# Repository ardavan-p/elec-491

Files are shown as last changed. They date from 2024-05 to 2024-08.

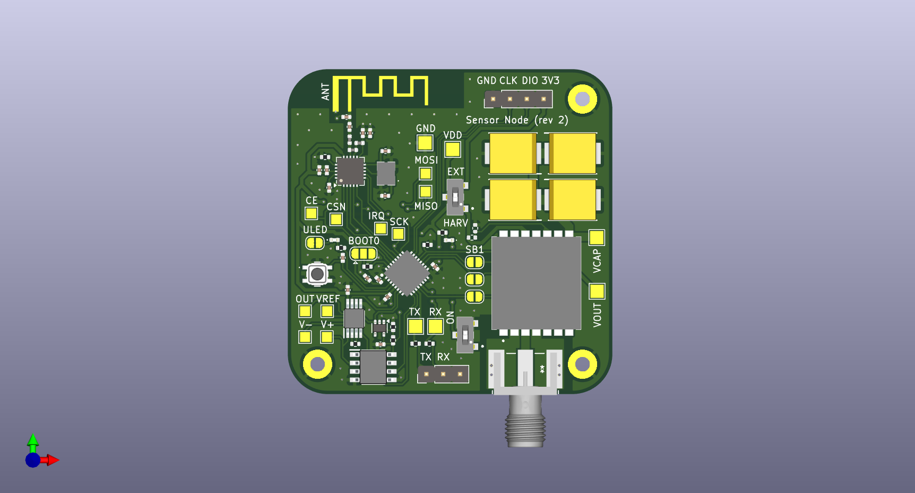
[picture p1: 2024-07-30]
sn/rev-2s/pcb/sensor-node-rev-2s/sensor-node-rev-2-img.png

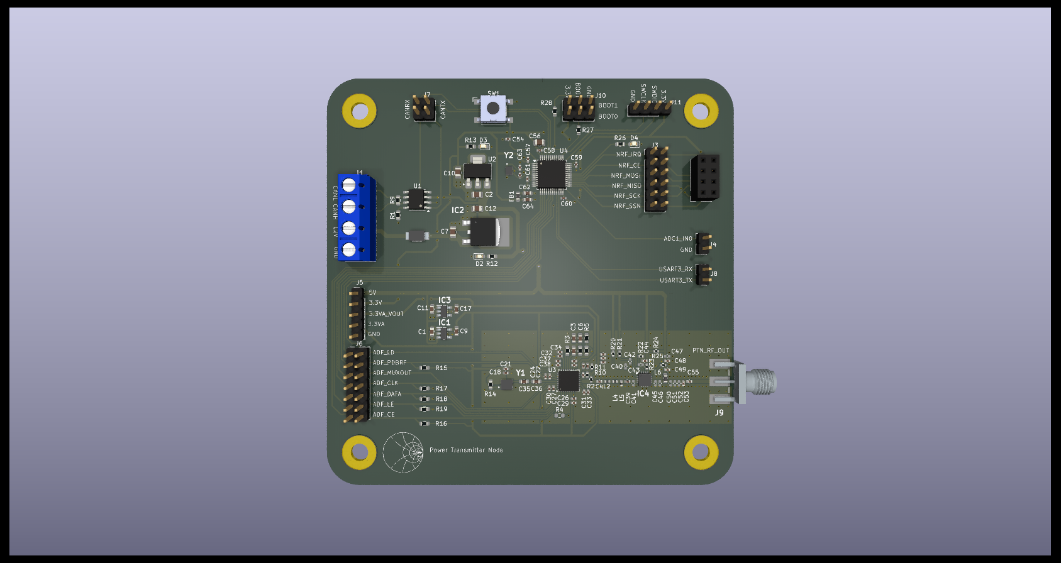
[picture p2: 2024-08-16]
video/scene3/ptn_image.png

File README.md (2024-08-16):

# ECE Capstone Project TL81 - Wirelessly Powered Tire Pressure Monitoring System

## Introduction
The following repository contains all design components for UBC ECE capstone project TL81 - Wirelessly Powered Tire Pressure Monitoring System

## Design Components
The following directories contain primary design components. 

### Graphical User Interface for TPMS
The source code for the GUI which was designed for demonstration purposes is located in the `gui/` folder. It is design in the Python.

### ECU Source Code
The firmware for the master ECU used in the demonstration is located in the `ecu/` folder. It is all written in C, for the STM32F103RCT6 microcontroller.

### Power Transmitter Node
All design files for the power transmitter node is located in the `ptn/` and `enclosure/ptn/` directories. <br>

The PCB design files for the power transmitter node are located in `ptn/pcb/`. The PCB is designed using the KiCad PCB design software. <br>

The firmware source code for the power transmitter node is located in `ptn/fw/`. It is all written in C, for the STM32F103C8T6 microcontroller. <br>

The physical enclosure for the power transmitter node is located in `enclosure/ptn/`. The PTN enclosure was designed using SolidWorks.

### Sensor Node
All design files for the sensor node is located in the `sn/` directory. <br>

The PCB design files for the sensor node are located in `sn/rev-2/pcb/sensor-node-v2/`. The PCB is designed using the KiCad PCB design software. <br>

The firmware source code for the final revision of the sensor node is located in `sn/rev-2/fw/sensor-node-v2/`. It is all written in C, for the STM32U031K8U6 microcontroller. <br>

## Capstone Video
All assets for the video created for this project is located in the `video/` folder.

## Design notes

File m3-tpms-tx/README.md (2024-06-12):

Contains the firmware for the TPMS sensor node.

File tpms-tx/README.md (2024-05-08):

Contains code for the prototype TPMS transmitter.

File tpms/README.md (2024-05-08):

Contains code for the prototype TPMS receiver.

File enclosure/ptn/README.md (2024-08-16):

# elec-391/enclosures/ptn

# Enclosure for the PTN

This directory includes the baseplate, top cover, and various PCB models (nRF24L014 and PTN PCBs) for the PTN enclosure.

The entire assembly is provided as a pack and go zip file, named "Assembly_pack_and_go.zip".

The two assembly components are also available as STL files for ease of viewing - "baseplate.STL" and "top_cover.STL".

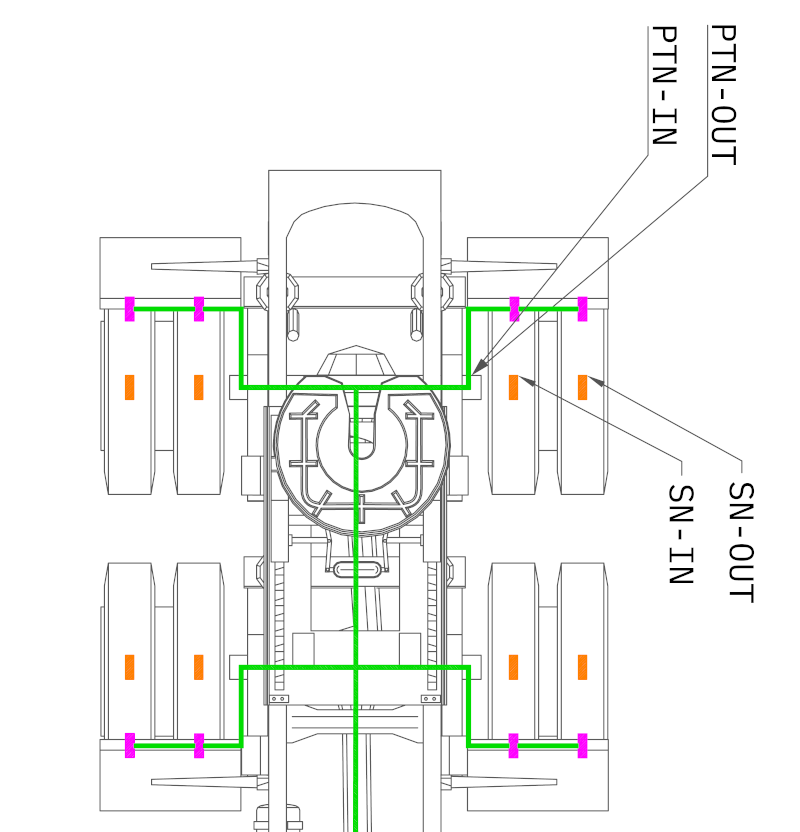
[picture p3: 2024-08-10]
gui/assets/truck-downsized.png

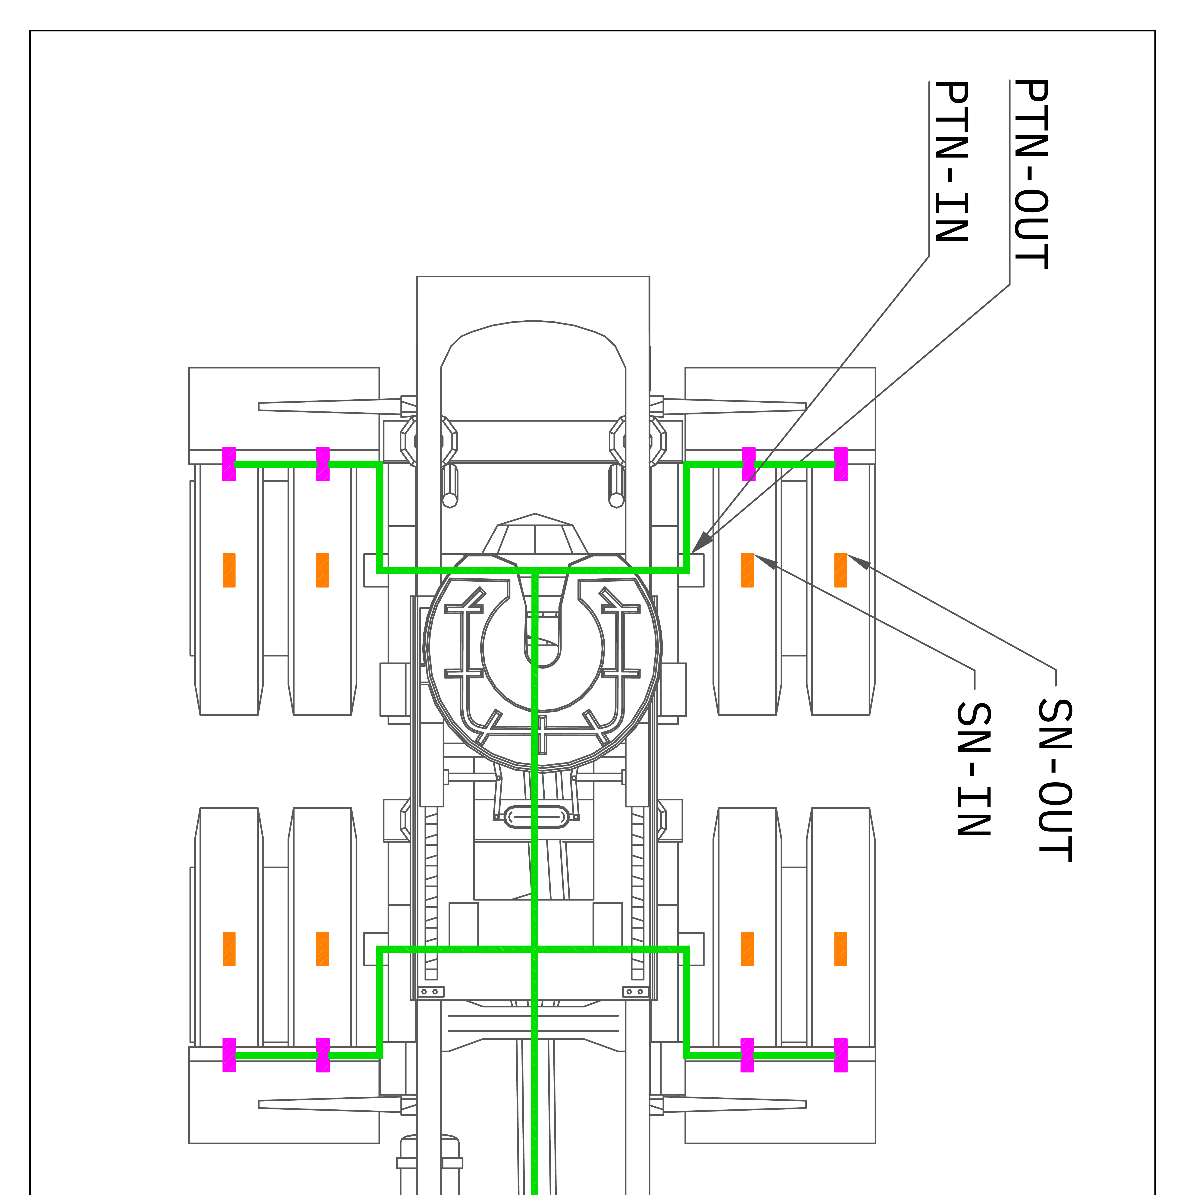
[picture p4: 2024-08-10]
gui/assets/truck.png

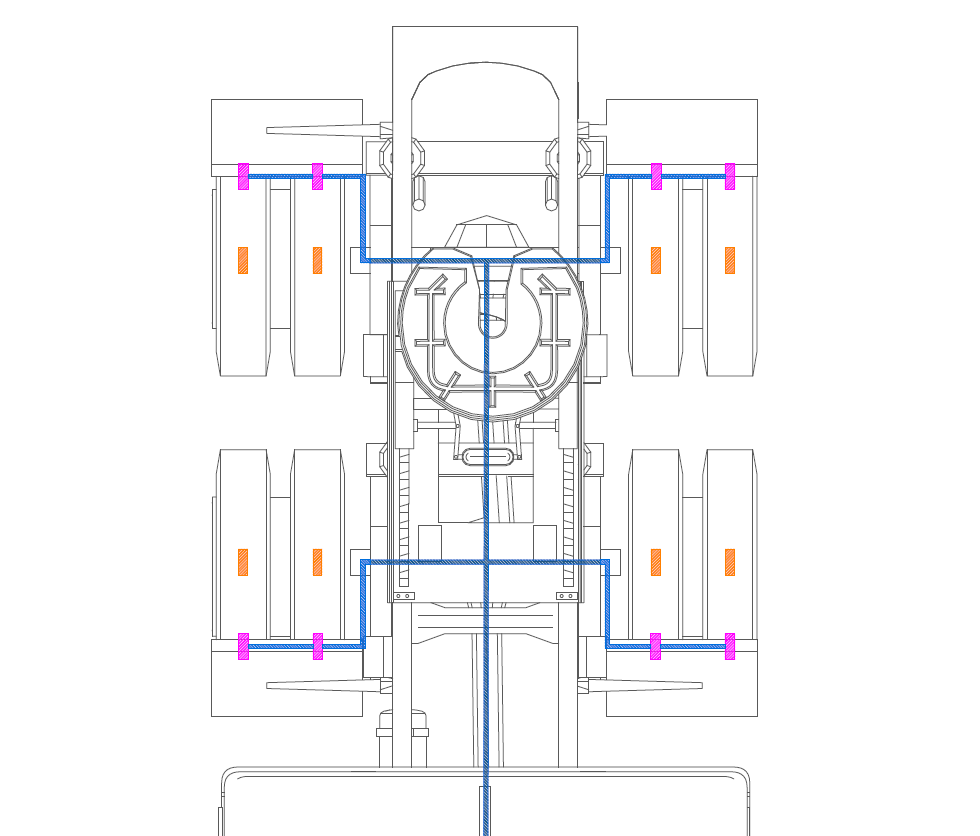
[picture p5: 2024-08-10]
gui/assets/gui_visual_v2.png

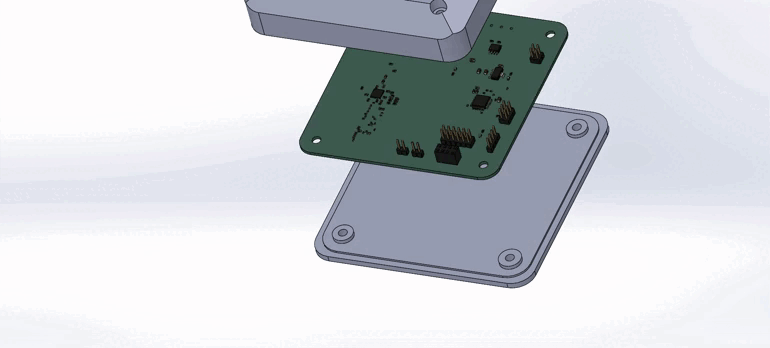
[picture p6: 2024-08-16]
enclosure/ptn/exports/Assem1.gif

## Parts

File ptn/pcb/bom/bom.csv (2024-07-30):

Reference | Guerrilla ID | Value | Description | Manufacturer_Name | Manufacturer_Part_Number | Mouser Part Number | Footprint | Qty | Datasheet | DNP
J1 |  | TB002-500-04BE | Fixed Terminal Blocks screw type, 5.00 , horizontal, 4 poles, CUI Blue, slotted screw, PCB mount | CUI Devices | TB002-500-04BE | 490-TB002-500-04BE | project_footprint_library:TB00250004BE_SCREW_TERMINAL | 1 | https://componentsearchengine.com/Datasheets/1/TB002-500-04BE.pdf
SW1 |  | SW_Push | Push button switch, generic, two pins | Omron Electronics | B3FS-1002P | 653-B3FS-1002P | Button_Switch_SMD:SW_SPST_Omron_B3FS-100xP | 1 | ~
U4 |  | STM32F103C8T6 | STMicroelectronics Arm Cortex-M3 MCU, 64KB flash, 20KB RAM, 72 MHz, 2.0-3.6V, 37 GPIO, LQFP48 | STMicroelectronics | STM32F103C8T6 | 511-STM32F103C8T6 | Package_QFP:LQFP-48_7x7mm_P0.5mm | 1 | https://www.st.com/resource/en/datasheet/stm32f103c8.pdf
Y1 |  | SIT5000AICGE-33E0-25.000000X | TCXO Oscillators 25MHz 3.3V -40C +85C 5ppm | SiTime | SIT5000AICGE-33E0-25.000000X | 788-5000AICGE3E0-25X | project_footprint_library:SIT5000AICGE33E025000000X | 1 | https://componentsearchengine.com/Datasheets/1/SIT5000AICGE-33N0-25.000000X.pdf
U2 |  | NCP1117-3.3_SOT223 | 1A Low drop-out regulator, Fixed Output 3.3V, SOT-223 | onsemi | NCP1117ST33T3G | 863-NCP1117ST33T3G | Package_TO_SOT_SMD:SOT-223-3_TabPin2 | 1 | http://www.onsemi.com/pub_link/Collateral/NCP1117-D.PDF
U1 |  | MCP2551-I-SN | High-Speed CAN Transceiver, 1Mbps, 5V supply, SOIC-8 | Microchip Technology | MCP2551-I/SN | 579-MCP2551-I/SN | Package_SO:SOIC-8_3.9x4.9mm_P1.27mm | 1 | http://ww1.microchip.com/downloads/en/devicedoc/21667d.pdf
D2,D3,D4 |  | LED | Light emitting diode 150060VS55040 | Wurth Elektronik | 150060VS55040 | 710-150060VS55040 | LED_SMD:LED_0603_1608Metric | 3 | ~
IC4 |  | GRF5509 | RF Amplifier High Efficiency, 5.0Watt PA/Saturated PA, OP1dB >34.0 dBm, 900 MHz ISM; 0.7 - 01.8 GHz | Guerrilla RF | GRF5509 | 459-GRF5509 | project_footprint_library:QFN50P300X300X85-17N | 1 | https://www.guerrilla-rf.com/products/DataSheet?sku=5509&file_name=GRF5509DS.pdf
D1 |  | D | Diode | ROHM Semiconductor | RF302LAM2STR | 755-RF302LAM2STR | project_footprint_library:RF302LAM2STR_DIODE | 1 | ~
IC2 |  | AZ1084CD-5.0TRG1 | Linear Voltage Regulator IC Positive Fixed 1 Output 5A TO-252-3 | Diodes Incorporated | AZ1084CD-5.0TRG1 | 621-AZ1084CD-5.0TRG1 | project_footprint_library:AZ1084CD50TRG1_LDO_5V | 1 | https://www.diodes.com//assets/Datasheets/AZ1084C.pdf
IC1,IC3 |  | ADP150AUJZ-3.3-R7 | Ultralow Noise, 150 mA CMOS Linear Regulator | Analog Devices | ADP150AUJZ-3.3-R7 | 584-ADP150AUJZ-3.3R7 | project_footprint_library:SOT95P280X100-5N | 2 | https://componentsearchengine.com/Datasheets/1/ADP150AUJZ-3.3-R7.pdf
U3 |  | ADF4351 | 35-4400MHz fractional-N PLL, LFCSP-32 | Analog Devices | ADF4351BCPZ-RL7 | 584-ADF4351BCPZ-R7 | Package_CSP:LFCSP-32-1EP_5x5mm_P0.5mm_EP3.25x3.25mm | 1 | https://www.analog.com/media/en/technical-documentation/data-sheets/ADF4351.pdf
J9 |  | 142-0701-801 | JOHNSON - 142-0701-801 - \u5C04\u9891/\u540C\u8F74\u63D2\u5B54, SMA, PCB\u5B89\u88C5 | Cinch Connectivity Solutions | 142-0701-801 | 530-142-0701-801 | project_footprint_library:142-0701-851 | 1
Y2 |  | 16MHz | Four pin crystal, GND on pins 2 and 4. Wurth PN: 830108288709 | Wurth Elektronik | 830108288709 | 710-830108288709 | project_footprint_library:16MHz_830108288709 | 1 | ~
R15,R16,R17,R18,R19,R27,R28 |  | 10k | Resistor | YAGEO | RT0603FRE1310KL | 603-RT0603FRE1310KL | Resistor_SMD:R_0603_1608Metric | 7 | ~
R21 | M3 | 6.8k | Resistor M3 | Panasonic | ERJ-2GEJ682X | 667-ERJ-2GEJ682X | Resistor_SMD:R_0402_1005Metric | 1 | ~
R3 |  | 5.1k | Resistor | Vishay / Dale | CRCW06035K10FKEC | 71-CRCW06035K10FKEC | Resistor_SMD:R_0603_1608Metric | 1 | ~
R20 | M1 | 3.3k | Resistor M1 | Panasonic | ERJ-2GEJ332X | 667-ERJ-2GEJ332X | Resistor_SMD:R_0402_1005Metric | 1 | ~
R14 |  | 2k | Resistor | YAGEO | RT0603FRE102KL | 603-RT0603FRE102KL | Resistor_SMD:R_0603_1608Metric | 1 | ~
R1,R6 |  | 1k | Resistor | YAGEO | RC0603FR-101KL | 603-RC0603FR-101KL | Resistor_SMD:R_0603_1608Metric | 2 | ~
R5 |  | 360R | Resistor | YAGEO | RT0603DRE07360RL | 603-RT0603DRE07360RL | Resistor_SMD:R_0603_1608Metric | 1 | ~
R12 |  | 250R | Resistor | YAGEO | RT0603BRE07250RL | 603-RT0603BRE07250RL | Resistor_SMD:R_0603_1608Metric | 1 | ~
R9 |  | 120R | Resistor | YAGEO | RC0603FR-10120RL | 603-RC0603FR-10120RL | Resistor_SMD:R_0603_1608Metric | 1 | ~
FB1 |  | 120R | Ferrite bead - 120 ohms at 100MHz | Bussmann / Eaton | MFBM1V1608-121-R | 704-MFBM1V1608-121-R | Inductor_SMD:L_0603_1608Metric | 1 | ~
R13,R26 |  | 100R | Resistor | YAGEO | RT0603DRE07100RL | 603-RT0603DRE07100RL | Resistor_SMD:R_0603_1608Metric | 2 | ~
R2,R10,R11 |  | 50R | Resistor | YAGEO | RC0402JR-0750RL | 603-RC0402JR-0750RL | Resistor_SMD:R_0402_1005Metric | 3 | ~
C12 |  | 22u | Unpolarized capacitor | Murata Electronics | GRM21BR61E226ME44K | 81-GRM21BR61E226ME4K | Capacitor_SMD:C_0805_2012Metric | 1 | ~
C2,C7,C10,C56 |  | 10u | Unpolarized capacitor | Murata Electronics | GRM21BR61E106KA73K | 81-GRM21BR61E106KA3K | Capacitor_SMD:C_0805_2012Metric | 4 | ~
C1,C9,C11,C17,C62,C64 |  | 1u | Unpolarized capacitor | KEMET | C0603C105K3PACTU | 80-C0603C105K3P | Capacitor_SMD:C_0603_1608Metric | 6 | ~
C19,C20,C21,C24,C28,C29,C30,C33,C34,C38,C44,C48,C54,C57,C58,C59,C60 | -- mixed values -- | 0.1u | -- mixed values -- | Murata Electronics | GRM155R71C104JA88J | 81-GRM155R71C104JA8J | Capacitor_SMD:C_0402_1005Metric | 17 | ~
C6 |  | 47n | Unpolarized capacitor | KEMET | C0603C473J3RACTU | 80-C0603C473J3R | Capacitor_SMD:C_0603_1608Metric | 1 | ~
L6 | M18 | 24n | Inductor M18 | Murata Electronics | LQW18AN24NG80D | 81-LQW18AN24NG80D | Inductor_SMD:L_0603_1608Metric | 1 | ~
C61 |  | 10n | Unpolarized capacitor | KEMET | C0402C103J8RACTU | 80-C0402C103J8RACTU | Capacitor_SMD:C_0402_1005Metric | 1 | ~
L1,L3 |  | 7.5n | Inductor | Murata Electronics | LQW15AN7N5G80D | 81-LQW15AN7N5G80D | Inductor_SMD:L_0402_1005Metric | 2 | ~ | DNP
L4,L5 | -- mixed values -- | 6.8n | -- mixed values -- | Murata Electronics | LQG15WH6N8G02D | 81-LQG15WH6N8G02D | Inductor_SMD:L_0402_1005Metric | 2 | ~
C3 |  | 2.7n | Unpolarized capacitor | KYOCERA AVX | 06031C272JAT2A | 581-06031C272JAT2A | Capacitor_SMD:C_0603_1608Metric | 1 | ~
L2 |  | 1.9n | Inductor | Murata Electronics | LQG15WZ1N9C02D | 81-LQG15WZ1N9C02D | Inductor_SMD:L_0402_1005Metric | 1 | ~
C8 |  | 1.2n | Unpolarized capacitor | KEMET | C0603C122J5RACTU | 80-C0603C122J5R | Capacitor_SMD:C_0603_1608Metric | 1 | ~
C35,C36 |  | 1n | Unpolarized capacitor | KYOCERA AVX | 06035A102JAT2A | 581-06035A102J | Capacitor_SMD:C_0603_1608Metric | 2 | ~
C5,C14 |  | 1n | Unpolarized capacitor | Murata Electronics | GRM1555C1H102FA01D | 81-GRM1555C1H102FA1D | Capacitor_SMD:C_0402_1005Metric | 2 | ~ | DNP
C16,C23 |  | 120p | Unpolarized capacitor | Murata Electronics | GRM1555C1H121FA01D | 81-GRM1555C1H121FA1D | Capacitor_SMD:C_0402_1005Metric | 2 | ~
C4,C13,C49 | -- mixed values -- | 100p | -- mixed values -- | Murata Electronics | GRM1555C1H101FA01D | 81-GRM1555C1H101FA1D | Capacitor_SMD:C_0402_1005Metric | 3 | ~
C55 | M23 | 20p | Unpolarized capacitor M23 | Murata Electronics | GJM1555C1H200FB01D | 81-GJM1555C1H200FB1D | Capacitor_SMD:C_0402_1005Metric | 1 | ~
C53 | M22 | 12p | Unpolarized capacitor M22 | Murata Electronics | GJM1555C1H120FB01D | 81-GJM1555C1H120FB1D | Capacitor_SMD:C_0402_1005Metric | 1 | ~
C15,C18,C22,C25,C26,C27,C31,C32,C37,C63,C65 |  | 10p | Unpolarized capacitor | Murata Electronics | GCM1555C1H100JA16J | 81-GCM1555C1H100JA6J | Capacitor_SMD:C_0402_1005Metric | 11 | ~
C39 | M4 | 5.6p | Unpolarized capacitor M4 | Murata Electronics | GJM1555C1H5R6WB01D | 81-GJM1555C1H5R6WB1D | Capacitor_SMD:C_0402_1005Metric | 1 | ~
R8,R22,R23,R24,R25 | -- mixed values -- | 0R | -- mixed values -- | Vishay / Dale | RCS04020000Z0ED | 71-RCS04020000Z0ED | Resistor_SMD:R_0402_1005Metric | 5 | ~ | -- mixed values --
R7 |  | 0R | Resistor | Vishay / Dale | RCS06030000Z0EA | 71-RCS06030000Z0EA | Resistor_SMD:R_0603_1608Metric | 1 | ~

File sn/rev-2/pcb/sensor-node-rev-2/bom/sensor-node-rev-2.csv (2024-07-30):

Reference | Value | Footprint | Qty | DNP | Manufacturer_Part_Number | Mouser Part Number
C1,C5,C6,C8 | C_Polarized | libtpms:CAPPM7362X375N | 4 |  | T520D108M2R5ATE030 | 80-T520D108M2R5ATE30
C2,C3,C4,C22,C23,C24 | 100n | Capacitor_SMD:C_0402_1005Metric | 6 |  | GRM155R61E104KA87J | 81-GRM155R61E104KA7J
C7 | 10u | Capacitor_SMD:C_0402_1005Metric | 1 |  | GRM155R60J106ME05D | 81-GRM155R60J106M05D
C9 | 33n | Capacitor_SMD:C_0402_1005Metric | 1 |  | GRM155R71H333KE14J | 81-GRM155R71H333KE4J
C10,C12 | 10p | Capacitor_SMD:C_0402_1005Metric | 2 |  | GCM1555G1H120GA16J | 81-GCM1555G1H120GA6J
C13 | 1n | Capacitor_SMD:C_0402_1005Metric | 1 |  | GRM1555C1H102GA01D | 81-GRM1555C1H102GA1D
C14 | 10n | Capacitor_SMD:C_0402_1005Metric | 1 |  | GRM155R71H103JA88D | 81-GRM155R71H103JA8D
C15 | 1.5pF | Capacitor_SMD:C_0402_1005Metric | 1 |  | VJ0402A1R5BXQPW1BC | 77-VJ0402A1R5BXQPBC
C16 | 1.0pF | Capacitor_SMD:C_0402_1005Metric | 1 |  | VJ0402A1R0BXQPW1BC | 77-VJ0402A1R0BXQPBC
C17 | 2.2nF | Capacitor_SMD:C_0402_1005Metric | 1 |  | GRM155R71H222JA01D | 81-GRM36X222J50
C18 | 4.7pF | Capacitor_SMD:C_0402_1005Metric | 1 |  | GCM1555C1H4R7BA16J | 81-GCM1555C1H4R7BA6J
D1,D2 | LED | LED_SMD:LED_0402_1005Metric | 2 |  | 150040GS73220 | 710-150040GS73220
IC1 | NPP-301A-700AT | libtpms:SOIC127P610X280-8N | 1 |  | NPP-301A-700AT | 527-NPP-301A-700AT
IC2 | AD8226ARMZ | libtpms:SOP65P490X110-8N | 1 |  | AD8226ARMZ | 584-AD8226ARMZ
J2 | DEBUG_CONN | Connector_PinHeader_2.54mm:PinHeader_1x04_P2.54mm_Vertical | 1
J3 | SMA EDGE CONN | libtpms:CONN_73251-1150_MOL | 1 |  | 901-10309 | 523-901-10309
J4 | UART_CONN | Connector_PinHeader_2.54mm:PinHeader_1x03_P2.54mm_Vertical | 1
L1 | 8.2nH | Inductor_SMD:L_0402_1005Metric | 1 |  | LQG15HS8N2H02D | 81-LQG15HS8N2H02D
L2 | 2.7nH | Inductor_SMD:L_0402_1005Metric | 1 |  | LQG15HN2N7C02D | 81-LQG15HN2N7C02D
L3 | 3.9nH | Inductor_SMD:L_0402_1005Metric | 1 |  | LQG15HZ3N9C02D | 81-LQG15HZ3N9C02D
PS1 | P2110B | libtpms:P2110B | 1 |  | P2110B | 582-P2110B
R1 | 100k | Resistor_SMD:R_0402_1005Metric | 1 |  | ERJ-U02J104X | 667-ERJ-U02J104X
R3 | 4.3M | Resistor_SMD:R_0402_1005Metric | 1 | DNP | CRCW04024M32FKED | 71-CRCW04024M32FKED
R4,R5 | 470R | Resistor_SMD:R_0402_1005Metric | 2 |  | ERJ-2RHD471X | 667-ERJ-2RHD471X
R6,R7 | 220R | Resistor_SMD:R_0402_1005Metric | 2 |  | ERJ-2RHD2200X | 667-ERJ-2RHD2200X
R8,R11,R14 | 22k | Resistor_SMD:R_0402_1005Metric | 3 |  | ERJ-H2RD2202X | 667-ERJ-H2RD2202X
R9 | 12.4k | Resistor_SMD:R_0402_1005Metric | 1 | DNP | ERJ-U02F1242X | 667-ERJ-U02F1242X
R10 | 1k | Resistor_SMD:R_0402_1005Metric | 1 |  | ERJ-2GEJ102X | 667-ERJ-2GEJ102X
R12 | 5.49k | Resistor_SMD:R_0402_1005Metric | 1 | DNP | ERJ-2RKF5491X | 667-ERJ-2RKF5491X
R13 | 49.9k | Resistor_SMD:R_0402_1005Metric | 1 |  | ERJ-2RKF4992X | 667-ERJ-2RKF4992X
R15 | 2.61k | Resistor_SMD:R_0402_1005Metric | 1 | DNP | ERJ-U02F2611X | 667-ERJ-U02F2611X
S1,S5 | CAS-120A1 | libtpms:CAS120A1 | 2 |  | CAS-120A1 | 229-CAS-120A1
S4 | Pushbutton switch | libtpms:TS2134035BK160SMTTR | 1 |  | TS21-34-035-BK-160-SMT-TR | 179-134035BK160SMTTR
TP1,TP2,TP3,TP4,TP5,TP6,TP9,TP10,TP11,TP12,TP13,TP14,TP15,TP16,TP17,TP18 | ~ | -- mixed values -- | 16 |  | RCT-0C | 279-RCT-0C
U1 | STM32U031K8U6 | libtpms:QFN50P500X500X60-33N-D | 1 |  | STM32U031K8U6 | 511-STM32U031K8U6
U2 | nRF24L01P | Package_DFN_QFN:QFN-20-1EP_4x4mm_P0.5mm_EP2.5x2.5mm | 1 |  | NRF24L01P | 949-NRF24L01P
U4 | TLV9001IDCK | Package_TO_SOT_SMD:SOT-353_SC-70-5 | 1 |  | TLV9001IDCKR | 595-TLV9001IDCKR
Y1 | Crystal_16MHz | libtpms:830064296 | 1 |  | 830064296 | 710-830064296

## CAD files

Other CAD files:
enclosure/ptn/downloaded_components/LFCSP-32-1EP_5x5mm_P0.5mm_EP3.6x3.6mm.SLDASM
enclosure/ptn/downloaded_components/PinHeader_2x06_P2.54mm_Vertical.SLDASM
enclosure/ptn/downloaded_components/PinHeader_1x05_P2.54mm_Vertical.SLDASM
enclosure/ptn/downloaded_components/R_0402_1005Metric.SLDASM
enclosure/ptn/downloaded_components/PinHeader_1x04_P2.54mm_Vertical.SLDASM
enclosure/ptn/downloaded_components/SOIC-8_3.9x4.9mm_P1.27mm.SLDASM
enclosure/ptn/downloaded_components/PinHeader_2x07_P2.54mm_Vertical.SLDASM
enclosure/ptn/downloaded_components/CQ assembly.SLDPRT
enclosure/ptn/downloaded_components/C_0603_1608Metric.SLDASM
enclosure/ptn/downloaded_components/LQFP-48_7x7mm_P0.5mm.SLDASM
enclosure/ptn/downloaded_components/PinHeader_2x02_P2.54mm_Vertical.SLDASM
enclosure/ptn/downloaded_components/C_0805_2012Metric.SLDASM
enclosure/ptn/downloaded_components/L_0603_1608Metric.SLDASM
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

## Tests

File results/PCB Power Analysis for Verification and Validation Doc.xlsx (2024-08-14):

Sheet: Variable Supply Voltage
 | Energy @ 3.3V |  | 0.0001282035201 | J |  | 0.0079872 |  | s |  | Supply Voltage | Energy (mJ) | Time (ms)
 | Energy @ 2.5V |  | 7.961003901e-05 | J |  | 0.00823296 |  | s |  | 3.3V | 0.1282035201 | 7.9872
 | Energy @ 2.0V |  | 5.409272399e-05 | J |  | 0.00851968 |  | s |  | 2.5V | 0.07961003901 | 8.23296
 |  |  |  |  |  |  |  |  |  | 2.0V | 0.05409272399 | 8.51968
Sample | Samples | Time (ms) | Volt avg 1 | Curr avg 1 | Current (mA) | Power (3.3V) | Power (mW) |  | Volt avg 1 | Curr avg 1 | Power (2.5V) |  | Volt avg 1 | Curr avg 1 | Current (mA) | Power (2.0V)
46549 | 0 | 0 | -7.15e-05 | 2.23e-05 | 0.02 | -1.59445e-09 | -1.59445e-06 |  | 0.000262 | 4.13e-05 | 1.08206e-08 |  | -0.00019 | -8.27e-05 | -0.08 | 1.5713e-08
46550 | 1 | 0.04096 | 0.000381 | 5.72e-05 | 0.06 | 2.17932e-08 | 2.17932e-05 |  | 0.001454 | 0.001214 | 1.765156e-06 |  | 0.00701 | 0.005061 | 5.06 | 3.547761e-05
46551 | 2 | 0.08192 | 0.418472 | 0.181958 | 181.96 | 0.07614432818 | 76.14432818 |  | 0.412321 | 0.152893 | 0.06304099465 |  | 0.409913 | 0.129401 | 129.40 | 0.05304315211
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

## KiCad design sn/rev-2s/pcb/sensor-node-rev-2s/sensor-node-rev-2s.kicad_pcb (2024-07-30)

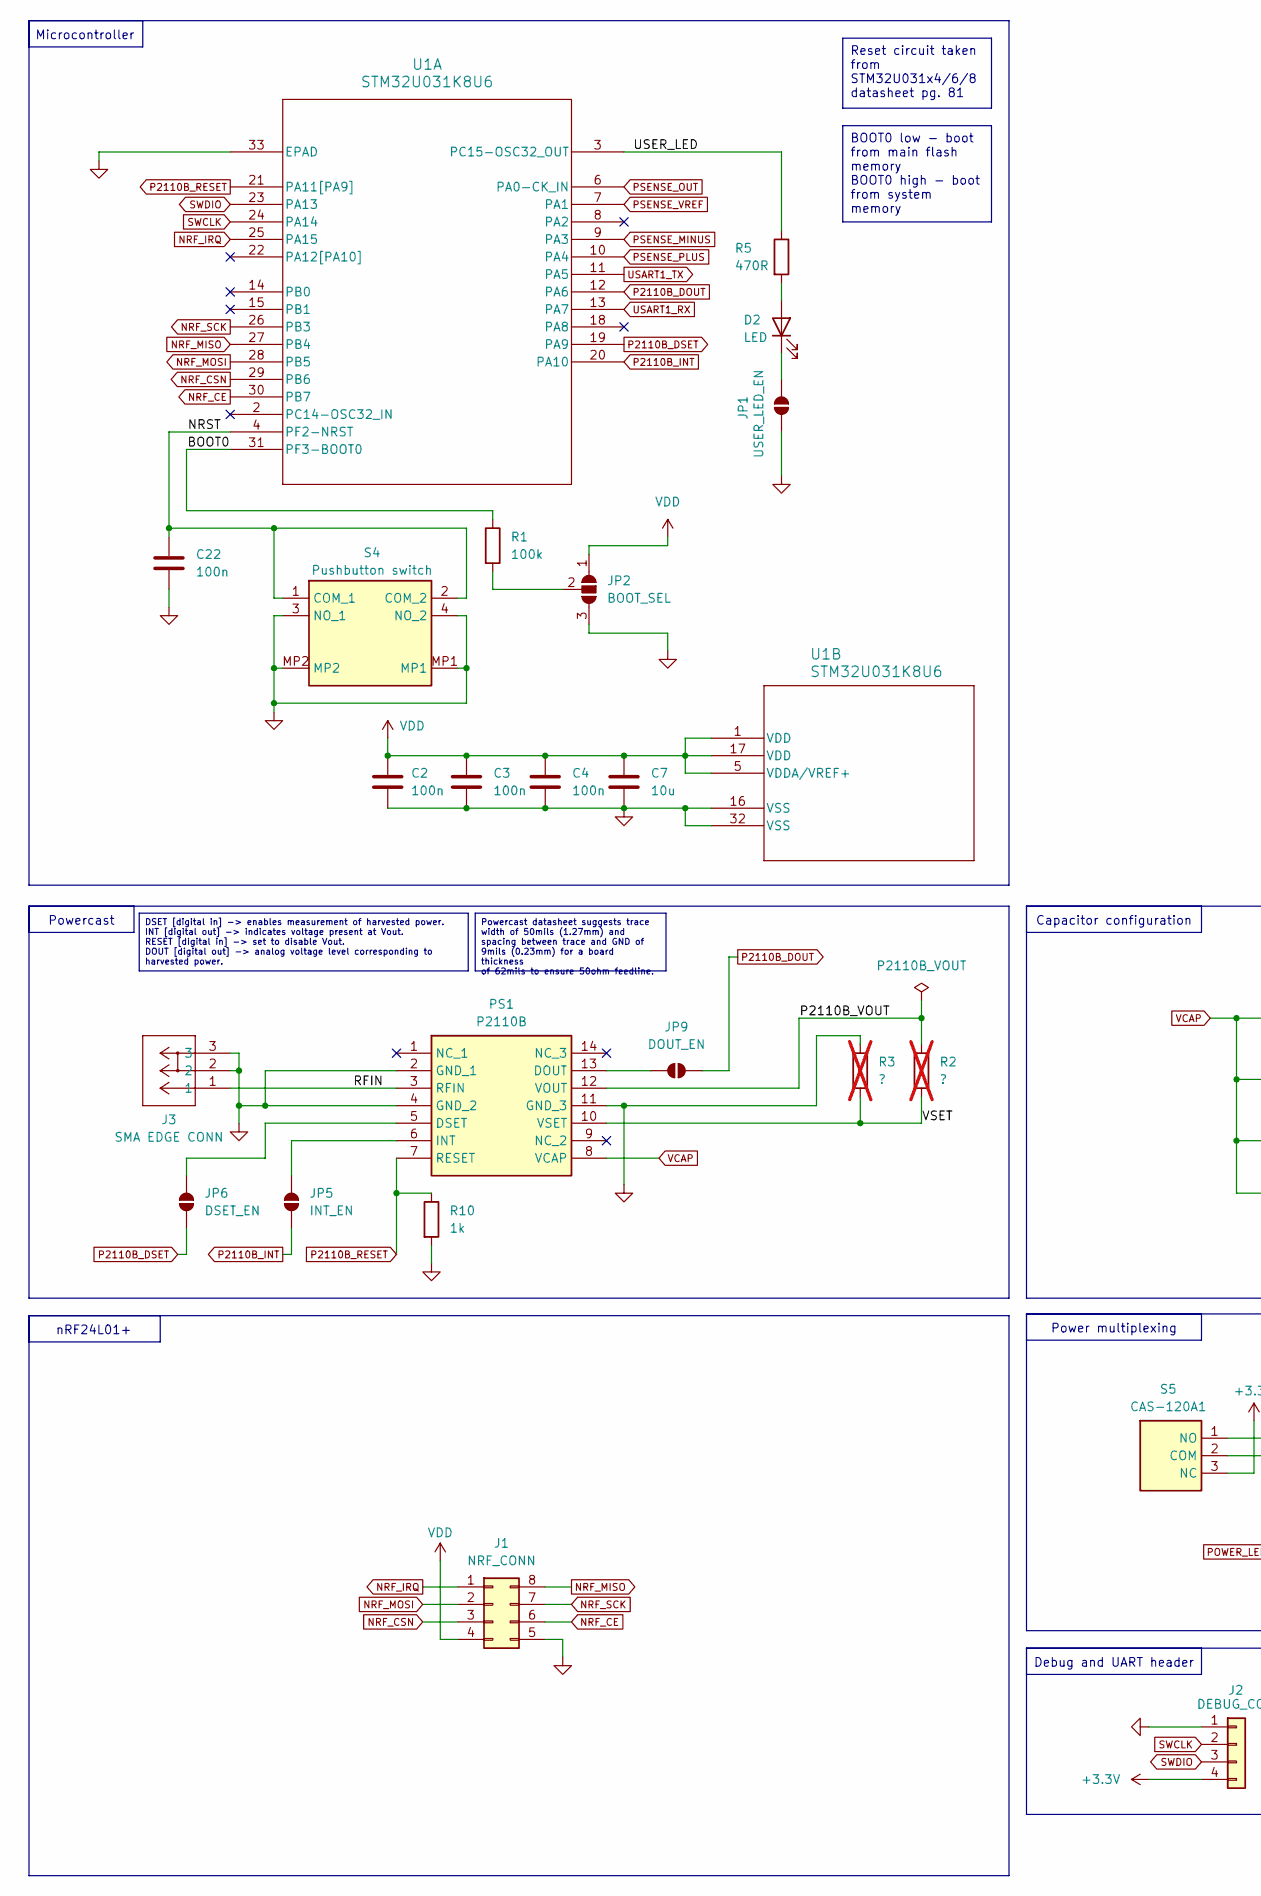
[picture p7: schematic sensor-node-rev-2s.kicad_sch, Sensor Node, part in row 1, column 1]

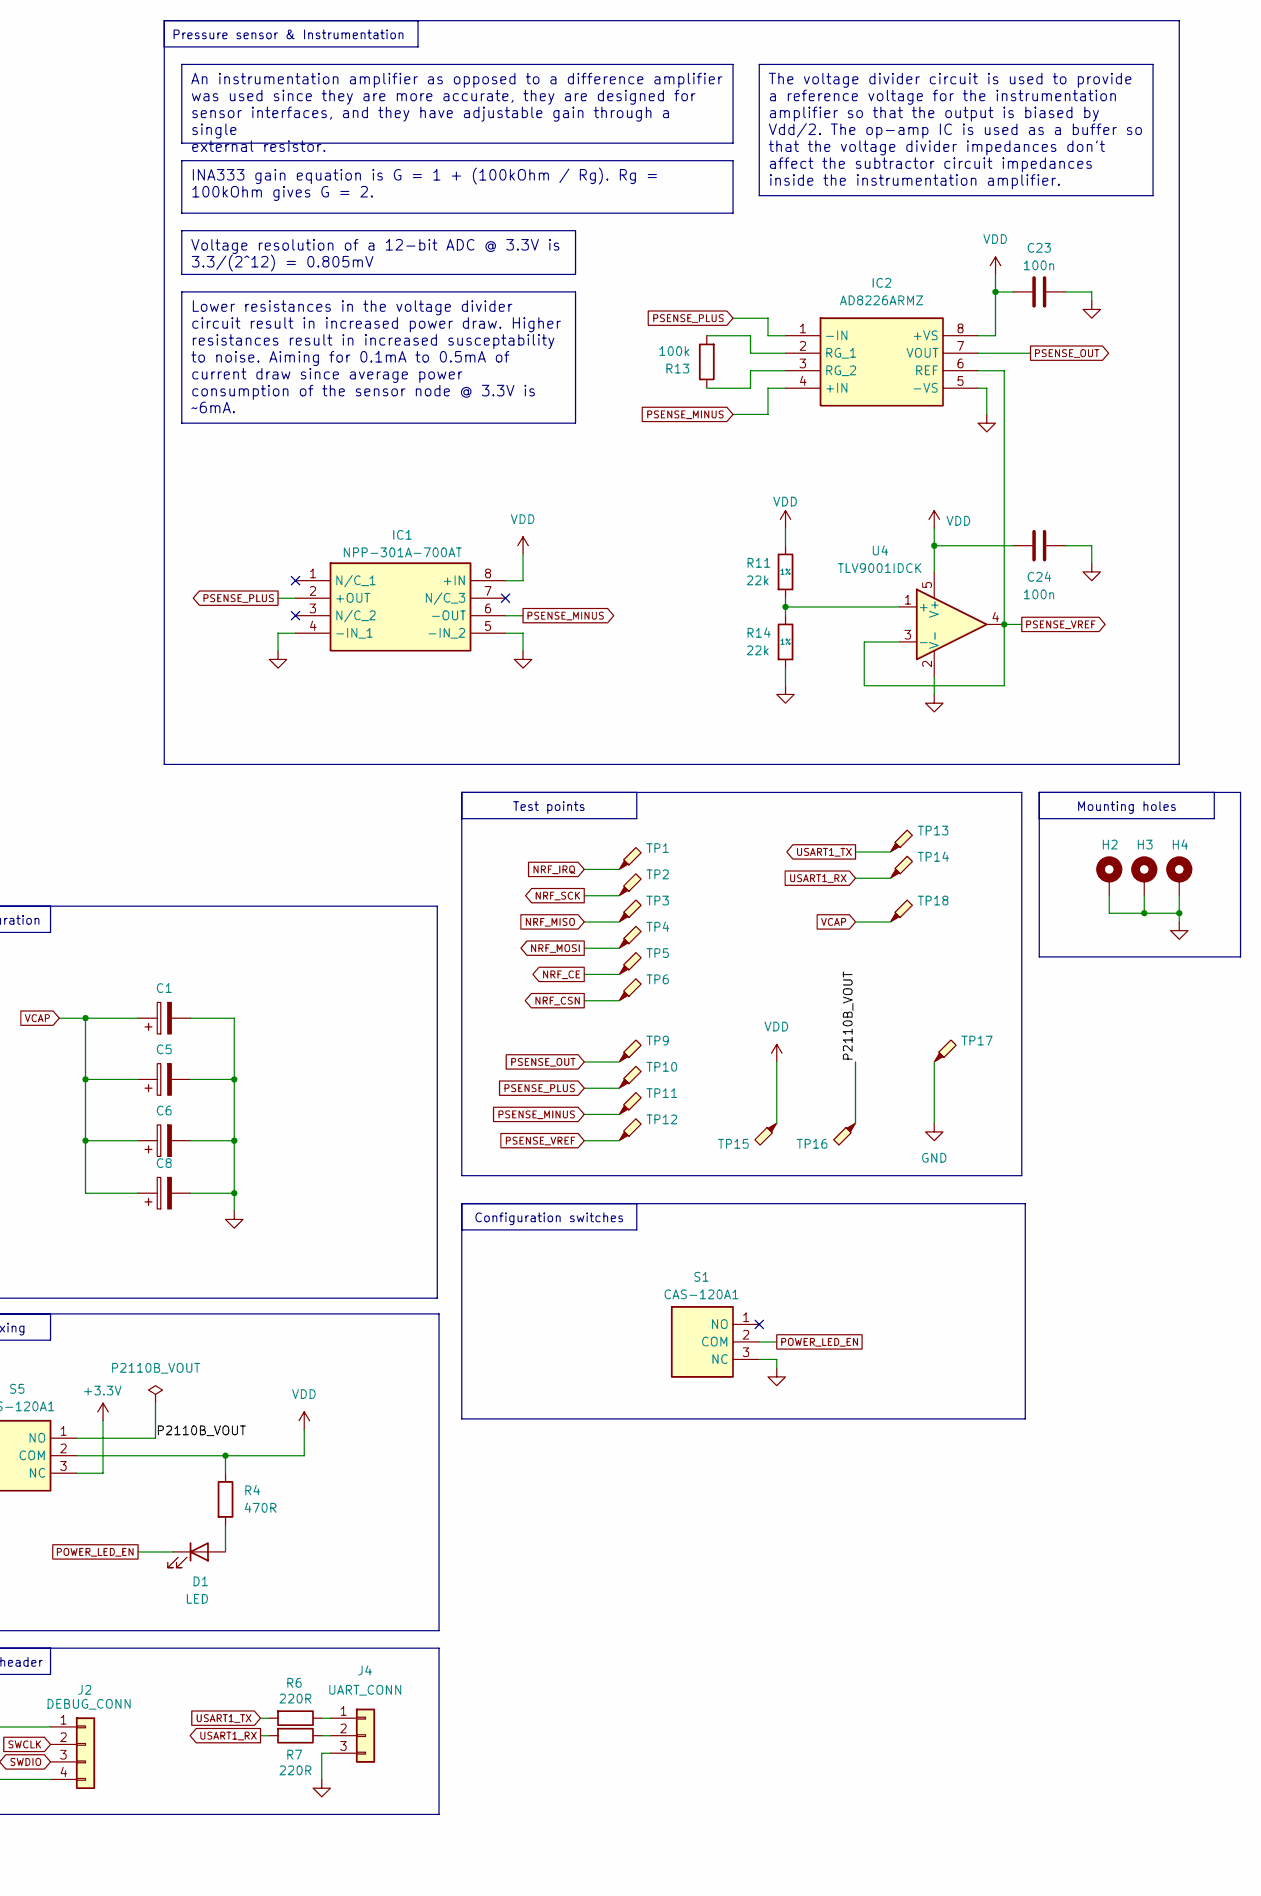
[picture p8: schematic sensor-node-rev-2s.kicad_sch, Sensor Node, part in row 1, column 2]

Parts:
C1, C5, C6, C8: C_Polarized; CAPPM7362X375N; Manufacturer_Part_Number F720J108MMCAQ2; Mouser Part Number 581-F720J108MMCAQ2
C2, C3, C4, C22, C23, C24: 100n; C_0402_1005Metric; Manufacturer_Part_Number 0402X7R104KT7AT; Mouser Part Number 581-0402X7R104KT7AT
C7: 10u; C_0402_1005Metric; Manufacturer_Part_Number GRM155R60J106ME05D; Mouser Part Number 81-GRM155R60J106M05D
D1, D2: LED; LED_0402_1005Metric; Manufacturer_Part_Number 150040GS73220; Mouser Part Number 710-150040GS73220
H2, H3, H4: MountingHole; MountingHole_2.2mm_M2_Pad
IC1: NPP-301A-700AT; SOIC127P610X280-8N; Mouser Part Number 527-NPP-301A-700AT
IC2: AD8226ARMZ; SOP65P490X110-8N; Mouser Part Number 584-AD8226ARMZ
J1: NRF_CONN; PinSocket_2x04_P2.54mm_Vertical; Manufacturer_Part_Number 90151-2104; Mouser Part Number 538-90151-2104
J2: DEBUG_CONN; PinHeader_1x04_P2.54mm_Vertical
J3: SMA EDGE CONN; CONN_73251-1150_MOL; Manufacturer_Part_Number 73251-1150; Mouser Part Number 538-73251-1150
J4: UART_CONN; PinHeader_1x03_P2.54mm_Vertical
JP1: USER_LED_EN; SolderJumper-2_P1.3mm_Open_RoundedPad1.0x1.5mm
JP2: BOOT_SEL; SolderJumper-3_P1.3mm_Open_RoundedPad1.0x1.5mm
JP5: INT_EN; SolderJumper-2_P1.3mm_Open_RoundedPad1.0x1.5mm
JP6: DSET_EN; SolderJumper-2_P1.3mm_Open_RoundedPad1.0x1.5mm
JP9: DOUT_EN; SolderJumper-2_P1.3mm_Open_RoundedPad1.0x1.5mm
PS1: P2110B; Mouser Part Number 582-P2110B
R1, R13: 100k; R_0402_1005Metric; Manufacturer_Part_Number ERJ-U02J104X; Mouser Part Number 667-ERJ-U02J104X
R2, R3: ?; R_0402_1005Metric; not fitted
R4, R5: 470R; R_0402_1005Metric; Manufacturer_Part_Number ERJ-2RHD471X; Mouser Part Number 667-ERJ-2RHD471X
R6, R7: 220R; R_0402_1005Metric; Manufacturer_Part_Number ERJ-2RHD2200X; Mouser Part Number 667-ERJ-2RHD2200X
R10: 1k; R_0402_1005Metric; Manufacturer_Part_Number ERJ-2GEJ102X; Mouser Part Number 667-ERJ-2GEJ102X
R11, R14: 22k; R_0402_1005Metric; Tolerance 1%; Manufacturer_Part_Number ERJ-H2RD2202X; Mouser Part Number 667-ERJ-H2RD2202X
S1, S5: CAS-120A1; CAS120A1; Mouser Part Number 229-CAS-120A1
S4: Pushbutton switch; TS2134035BK160SMTTR; Mouser Part Number 179-134035BK160SMTTR
TP1, TP2, TP3, TP4, TP5, TP6, TP9, TP10, TP11, TP12: TestPoint_Pad_1.5x1.5mm; Manufacturer_Part_Number RCT-0C; Mouser Part Number 279-RCT-0C
TP13, TP14, TP15, TP16, TP17, TP18: TestPoint_Pad_2.0x2.0mm; Manufacturer_Part_Number RCT-0C; Mouser Part Number 279-RCT-0C
U1: STM32U031K8U6; QFN50P500X500X60-33N-D; Manufacturer_Part_Number STM32U031K8U6; Mouser Part Number 511-STM32U031K8U6
U4: TLV9001IDCK; SOT-353_SC-70-5; Manufacturer_Part_Number TLV9001IDCKR; Mouser Part Number 595-TLV9001IDCKR

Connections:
+3.3V: J2.4, S5.3 (NC)
/BOOT0: R1.1, U1.31 (PF3-BOOT0)
/NRST: C22.1, S4.1 (COM_1), S4.2 (COM_2), U1.4 (PF2-NRST)
/P2110B_VOUT: PS1.12 (VOUT), R2.1, S5.1 (NO), TP16.1
/RFIN: J3.1, PS1.3 (RFIN)
/USER_LED: R5.1, U1.3 (PC15-OSC32_OUT)
/VSET: PS1.10 (VSET), R2.2, R3.2
GND: C1.2, C2.2, C3.2, C4.2, C5.2, C6.2, C7.2, C8.2, C22.2, C23.2, C24.2, H2.1, H3.1, H4.1, IC1.4 (-IN_1), IC1.5 (-IN_2), IC2.5 (-VS), J1.5, J2.1, J3.2, J3.3, J4.3, JP1.1 (A), JP2.3 (B), PS1.2 (GND_1), PS1.4 (GND_2), PS1.11 (GND_3), R3.1, R10.2, R14.2, S1.3 (NC), S4.3 (NO_1), S4.4 (NO_2), S4.MP1, S4.MP2, TP17.1, U1.16 (VSS), U1.32 (VSS), U1.33 (EPAD), U4.2 (V-); also elsewhere on the board
NRF_CE: J1.6, TP5.1, U1.30 (PB7); also elsewhere on the board
NRF_CSN: J1.3, TP6.1, U1.29 (PB6); also elsewhere on the board
NRF_IRQ: J1.1, TP1.1, U1.25 (PA15); also elsewhere on the board
NRF_MISO: J1.8, TP3.1, U1.27 (PB4); also elsewhere on the board
NRF_MOSI: J1.2, TP4.1, U1.28 (PB5); also elsewhere on the board
NRF_SCK: J1.7, TP2.1, U1.26 (PB3); also elsewhere on the board
unnamed: D1.2 (A), R4.2
unnamed: D2.2 (A), R5.2
unnamed: D2.1 (K), JP1.2 (B)
unnamed: IC2.2 (RG_1), R13.2
unnamed: IC2.3 (RG_2), R13.1
unnamed: J4.1, R6.1
unnamed: J4.2, R7.1
unnamed: JP2.2 (C), R1.2
unnamed: JP5.2 (B), PS1.6 (INT)
unnamed: JP6.2 (B), PS1.5 (DSET)
unnamed: JP9.2 (B), PS1.13 (DOUT)
unnamed: R11.2, R14.1, U4.1 (+)
P2110B_DOUT: JP9.1 (A), U1.12 (PA6)
P2110B_DSET: JP6.1 (A), U1.19 (PA9)
P2110B_INT: JP5.1 (A), U1.20 (PA10)
P2110B_RESET: PS1.7 (RESET), R10.1, U1.21 (PA11[PA9])
POWER_LED_EN: D1.1 (K), S1.2 (COM)
PSENSE_MINUS: IC1.6 (-OUT), IC2.4 (+IN), TP11.1, U1.9 (PA3)
PSENSE_OUT: IC2.7 (VOUT), TP9.1, U1.6 (PA0-CK_IN)
PSENSE_PLUS: IC1.2 (+OUT), IC2.1 (-IN), TP10.1, U1.10 (PA4)
PSENSE_VREF: IC2.6 (REF), TP12.1, U1.7 (PA1), U4.3 (-), U4.4
SWCLK: J2.2, U1.24 (PA14)
SWDIO: J2.3, U1.23 (PA13)
USART1_RX: R7.2, TP14.1, U1.13 (PA7)
USART1_TX: R6.2, TP13.1, U1.11 (PA5)
VCAP: C1.1, C5.1, C6.1, C8.1, PS1.8 (VCAP), TP18.1
VDD: C2.1, C3.1, C4.1, C7.1, C23.1, C24.1, IC1.8 (+IN), IC2.8 (+VS), J1.4, JP2.1 (A), R4.1, R11.1, S5.2 (COM), TP15.1, U1.1 (VDD), U1.5 (VDDA/VREF+), U1.17 (VDD), U4.5 (V+); also elsewhere on the board

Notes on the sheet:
Reset circuit taken from STM32U031x4/6/8 datasheet pg. 81
Lower resistances in the voltage divider circuit result in increased power draw. Higher resistances result in increased susceptability to noise. Aiming for 0.1mA to 0.5mA of current draw since average power consumption of the sensor node @ 3.3V is ~6mA.
INA333 gain equation is G = 1 + (100kOhm / Rg). Rg = 100kOhm gives G = 2.
Voltage resolution of a 12-bit ADC @ 3.3V is 3.3/(2^12) = 0.805mV
Powercast datasheet suggests trace width of 50mils (1.27mm) and spacing between trace and GND of 9mils (0.23mm) for a board thickness of 62mils to ensure 50ohm feedline.
The voltage divider circuit is used to provide a reference voltage for the instrumentation amplifier so that the output is biased by Vdd/2. The op-amp IC is used as a buffer so that the voltage divider impedances don't affect the subtractor circuit impedances inside the instrumentation amplifier.
An instrumentation amplifier as opposed to a difference amplifier was used since they are more accurate, they are designed for sensor interfaces, and they have adjustable gain through a single external resistor.
BOOT0 low - boot from main flash memory BOOT0 high - boot from system memory
DSET [digital in] -> enables measurement of harvested power. INT [digital out] -> indicates voltage present at Vout. RESET [digital in] -> set to disable Vout. DOUT [digital out] -> analog voltage level corresponding to harvested power.
Test points
Capacitor configuration
nRF24L01+
Microcontroller
Powercast
Power multiplexing
Configuration switches
Debug and UART header
Mounting holes
Pressure sensor & Instrumentation

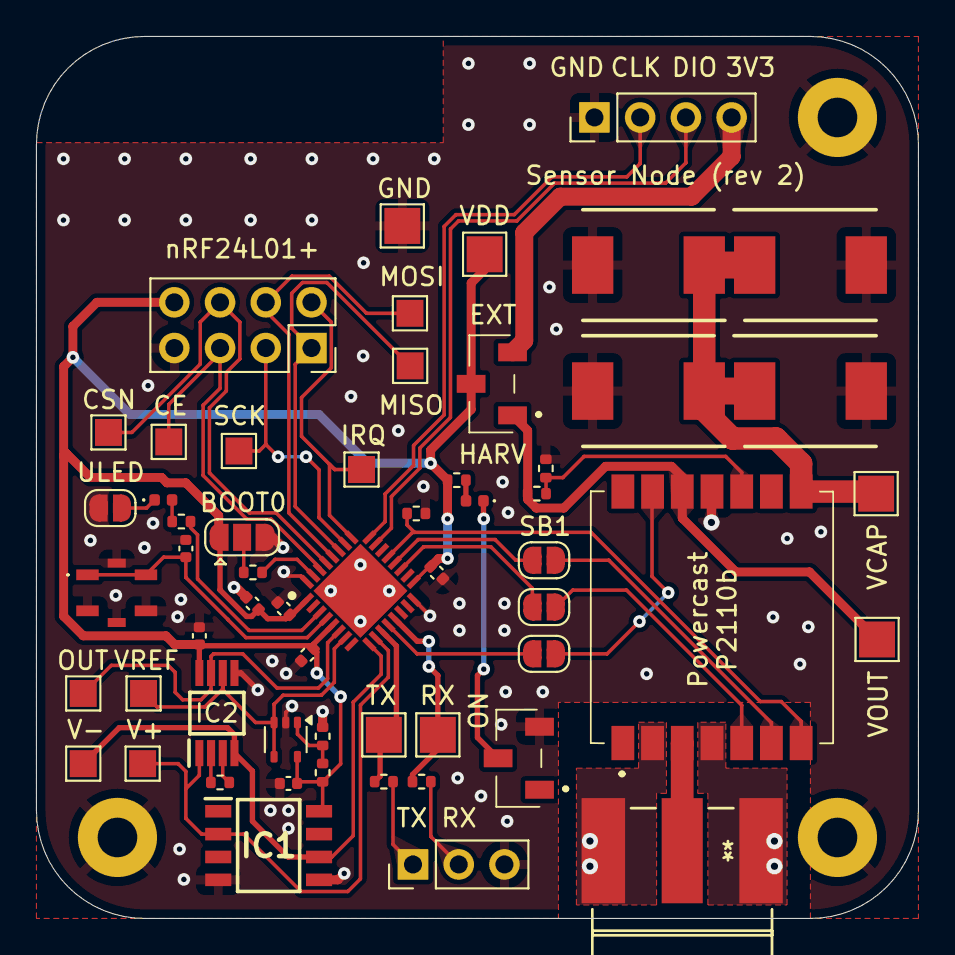
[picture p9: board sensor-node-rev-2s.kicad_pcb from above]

Board: 2 copper layers, 49.0 x 49.0 mm, 60 parts (0 on the bottom side), 41 nets.

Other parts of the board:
nRF24L01+: NRF_CONN; PinSocket_2x04_P2.54mm_Vertical

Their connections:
GND: nRF24L01+.5; also elsewhere on the board
NRF_CE: nRF24L01+.6; also elsewhere on the board
NRF_CSN: nRF24L01+.3; also elsewhere on the board
NRF_IRQ: nRF24L01+.1; also elsewhere on the board
NRF_MISO: nRF24L01+.8; also elsewhere on the board
NRF_MOSI: nRF24L01+.2; also elsewhere on the board
NRF_SCK: nRF24L01+.7; also elsewhere on the board
VDD: nRF24L01+.4; also elsewhere on the board

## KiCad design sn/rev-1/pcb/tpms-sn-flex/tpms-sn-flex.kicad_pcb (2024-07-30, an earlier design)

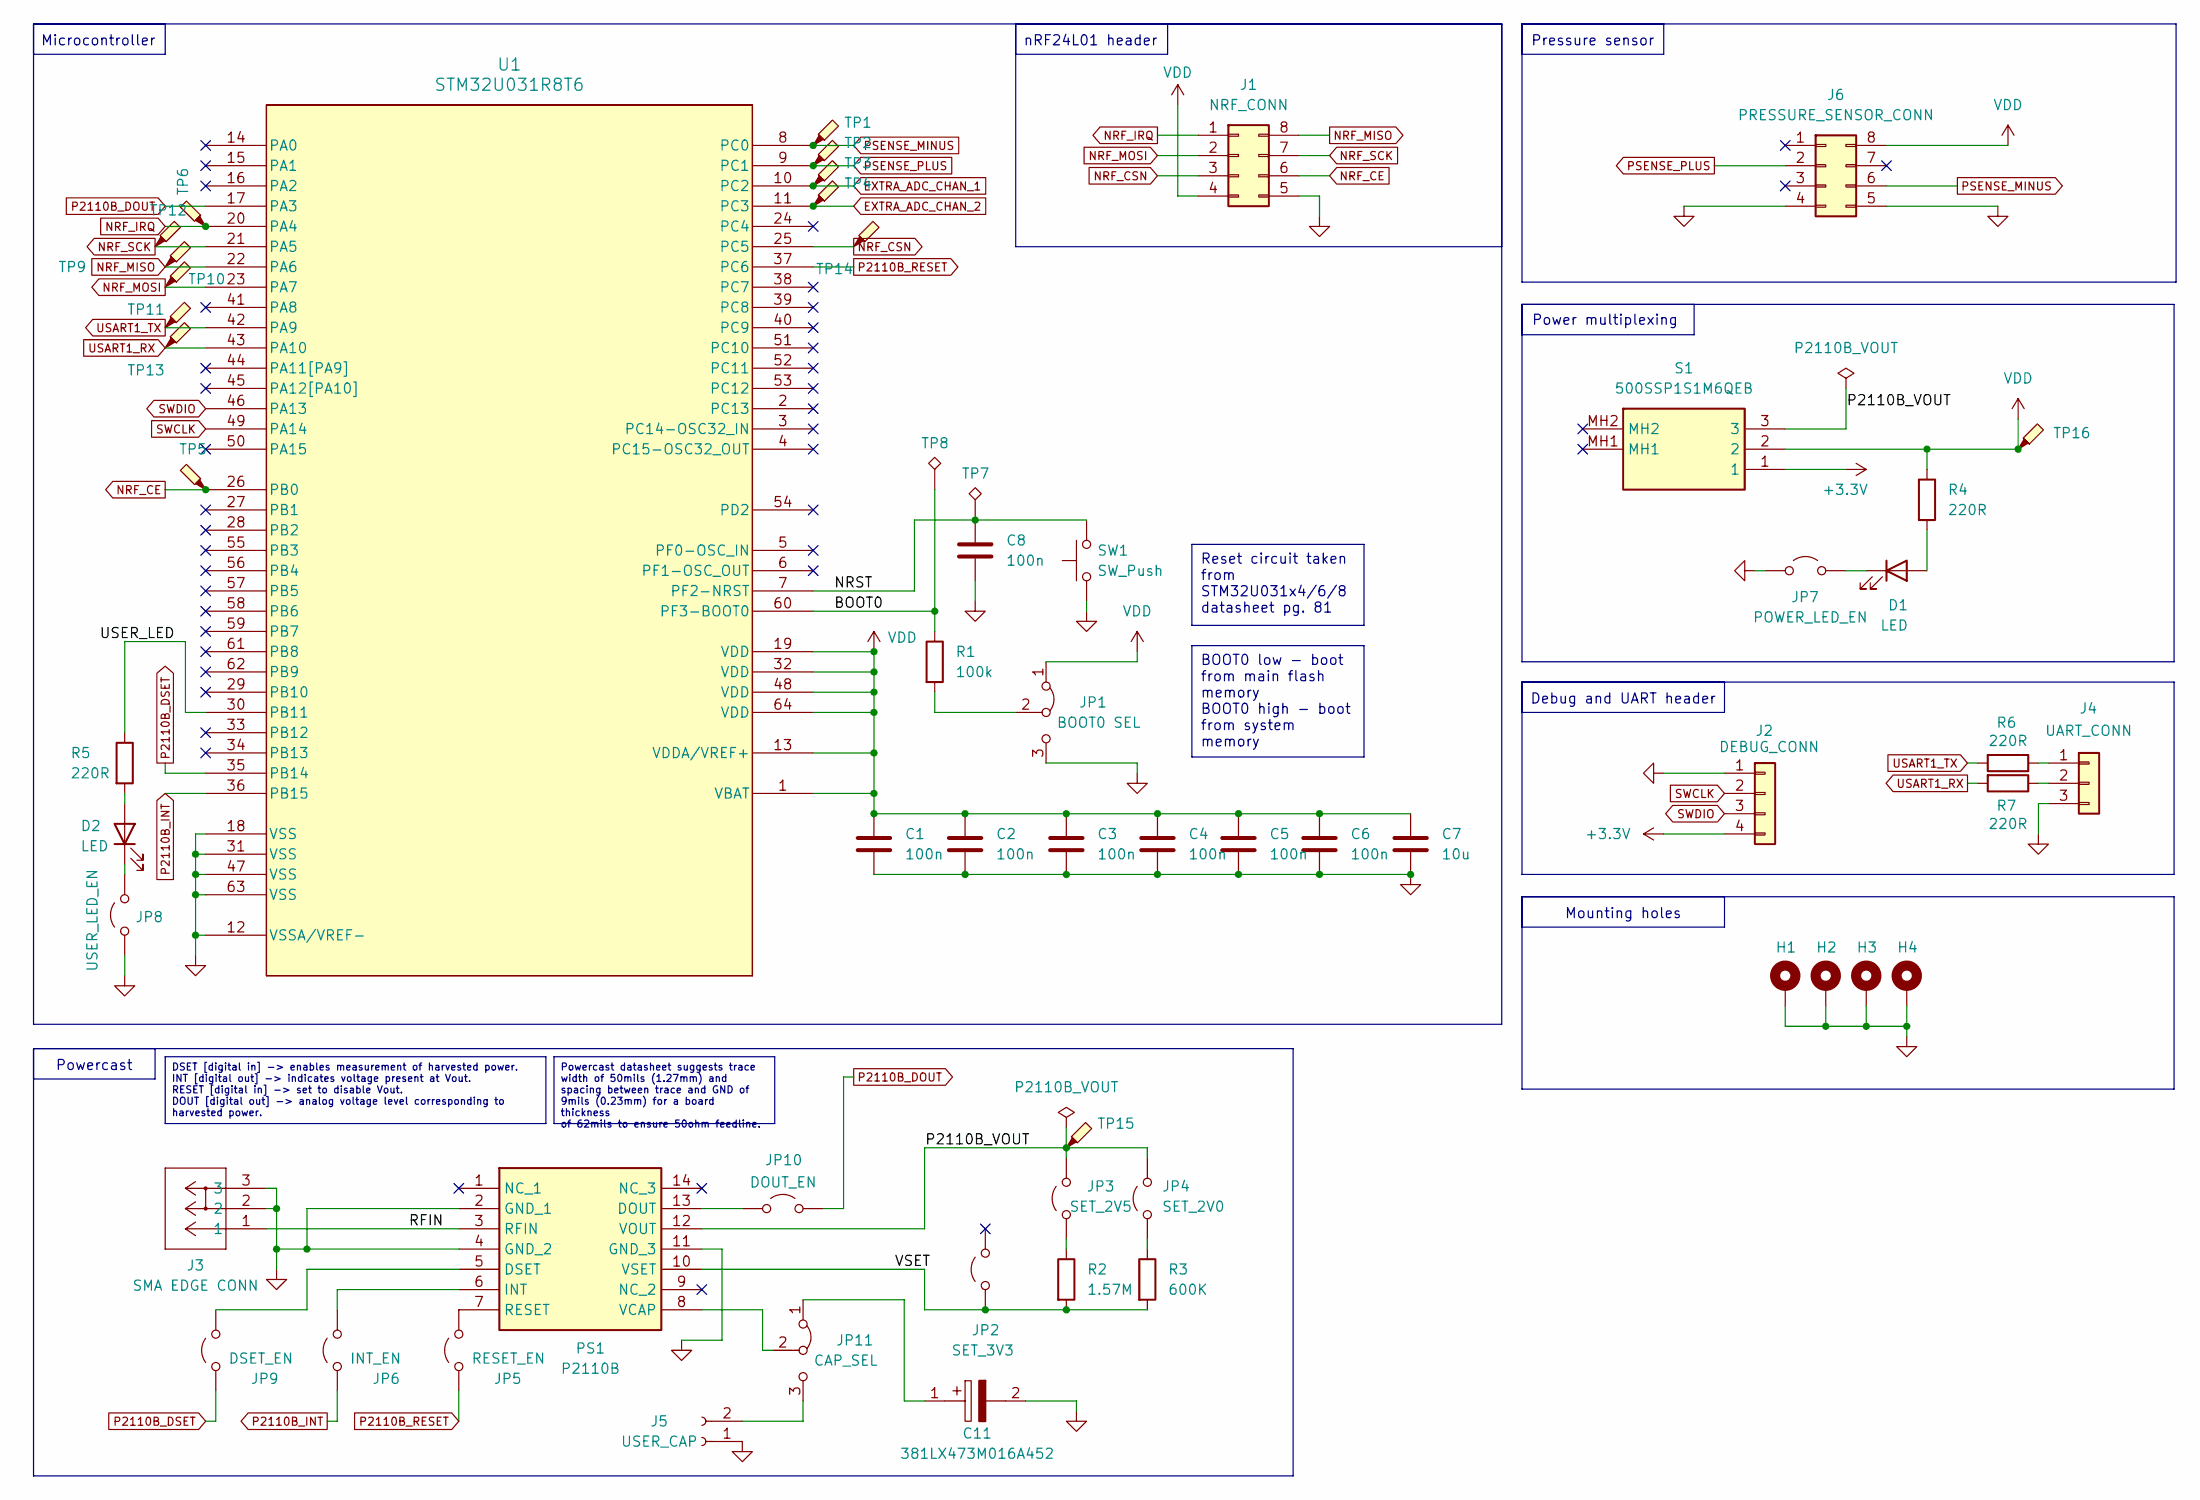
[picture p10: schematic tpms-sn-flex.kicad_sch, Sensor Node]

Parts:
C1, C2, C3, C4, C5, C6, C8: 100n; C_0603_1608Metric; Manufacturer_Part_Number KAM15AR71H104KM; Mouser Part Number 581-KAM15AR71H104KM
C7: 10u; C_0603_1608Metric; Manufacturer_Part_Number GRM188R60J106KE47J; Mouser Part Number 81-GRM188R60J106KE7J
C11: 381LX473M016A452; CAPPRD1000W200D3550H4700; Mouser Part Number 598-81LX473M016A452
D1, D2: LED; LED_0603_1608Metric; Manufacturer_Part_Number 150060GS55040; Mouser Part Number 710-150060GS55040
H1, H2, H3, H4: MountingHole; MountingHole_2.2mm_M2_Pad
J1: NRF_CONN; PinSocket_2x04_P2.54mm_Vertical; Manufacturer_Part_Number 90151-2104; Mouser Part Number 538-90151-2104
J2: DEBUG_CONN; PinHeader_1x04_P2.54mm_Vertical
J3: SMA EDGE CONN; CONN_73251-1150_MOL; Manufacturer_Part_Number 73251-1150; Mouser Part Number 538-73251-1150
J4: UART_CONN; PinHeader_1x03_P2.54mm_Vertical
J5: USER_CAP; PinSocket_1x02_P2.54mm_Vertical
J6: PRESSURE_SENSOR_CONN; 8-SOIC-DIP-8-ADAPTER
JP1: BOOT0 SEL; PinHeader_1x03_P2.54mm_Vertical
JP2: SET_3V3; PinHeader_1x02_P2.54mm_Vertical
JP3: SET_2V5; PinHeader_1x02_P2.54mm_Vertical
JP4: SET_2V0; PinHeader_1x02_P2.54mm_Vertical
JP5: RESET_EN; PinHeader_1x02_P2.54mm_Vertical
JP6: INT_EN; PinHeader_1x02_P2.54mm_Vertical
JP7: POWER_LED_EN; PinHeader_1x02_P2.54mm_Vertical
JP8: USER_LED_EN; PinHeader_1x02_P2.54mm_Vertical
JP9: DSET_EN; PinHeader_1x02_P2.54mm_Vertical
JP10: DOUT_EN; PinHeader_1x02_P2.54mm_Vertical
JP11: CAP_SEL; PinHeader_1x03_P2.54mm_Vertical
PS1: P2110B; Mouser Part Number 582-P2110B
R1: 100k; R_0603_1608Metric; Manufacturer_Part_Number ERJ-PA3D1003V; Mouser Part Number 667-ERJ-PA3D1003V
R2: 1.57M; R_0603_1608Metric; Manufacturer_Part_Number CRCW06031M58FKEA; Mouser Part Number 71-CRCW06031M58FKEA
R3: 600K; R_0603_1608Metric; Manufacturer_Part_Number ERJ-S03F6043V; Mouser Part Number 667-ERJ-S03F6043V
R4, R5, R6, R7: 220R; R_0603_1608Metric; Manufacturer_Part_Number ERJ-PA3D2200V; Mouser Part Number 667-ERJ-PA3D2200V
S1: 500SSP1S1M6QEB; Mouser Part Number 612-500SSP1S1M6QEB
SW1: SW_Push; SW_SPST_Omron_B3FS-100xP; Manufacturer_Part_Number B3FS-1002P; Mouser Part Number 653-B3FS-1002P
TP1, TP2, TP3, TP4, TP5, TP6: TestPoint_Probe; TestPoint_Pad_2.0x2.0mm; Manufacturer_Part_Number RCT-0C; Mouser Part Number 279-RCT-0C
TP7, TP8: TestPoint_Alt; TestPoint_Pad_2.0x2.0mm; Manufacturer_Part_Number RCT-0C; Mouser Part Number 279-RCT-0C
TP9, TP10, TP11, TP12, TP13, TP14, TP15, TP16: TestPoint_Pad_2.0x2.0mm; Manufacturer_Part_Number RCT-0C; Mouser Part Number 279-RCT-0C
U1: STM32U031R8T6; LQFP64_STM; Manufacturer_Part_Number STM32U031R8T6; Mouser Part Number 511-STM32U031R8T6

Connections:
+3.3V: J2.4, S1.1
/BOOT0: R1.1, TP8.1, U1.60 (PF3-BOOT0)
/NRST: C8.1, SW1.2, TP7.1, U1.7 (PF2-NRST)
/P2110B_VOUT: JP3.2 (B), JP4.2 (B), PS1.12 (VOUT), S1.3, TP15.1
/RFIN: J3.1, PS1.3 (RFIN)
/USER_LED: R5.1, U1.30 (PB11)
/VSET: JP2.1 (A), PS1.10 (VSET), R2.2, R3.2
EXTRA_ADC_CHAN_1: TP3.1, U1.10 (PC2)
EXTRA_ADC_CHAN_2: TP4.1, U1.11 (PC3)
GND: C1.2, C2.2, C3.2, C4.2, C5.2, C6.2, C7.2, C8.2, C11.2, H1.1, H2.1, H3.1, H4.1, J1.5, J2.1, J3.2, J3.3, J4.3, J5.1, J6.4, J6.5, JP1.3 (B), JP7.1 (A), JP8.1 (A), PS1.2 (GND_1), PS1.4 (GND_2), PS1.11 (GND_3), SW1.1, U1.12 (VSSA/VREF-), U1.18 (VSS), U1.31 (VSS), U1.47 (VSS), U1.63 (VSS)
NRF_CE: J1.6, TP5.1, U1.26 (PB0)
NRF_CSN: J1.3, TP14.1, U1.25 (PC5)
NRF_IRQ: J1.1, TP6.1, U1.20 (PA4)
NRF_MISO: J1.8, TP9.1, U1.22 (PA6)
NRF_MOSI: J1.2, TP10.1, U1.23 (PA7)
NRF_SCK: J1.7, TP12.1, U1.21 (PA5)
unnamed: D1.2 (A), R4.2
unnamed: D1.1 (K), JP7.2 (B)
unnamed: D2.2 (A), R5.2
unnamed: D2.1 (K), JP8.2 (B)
unnamed: J4.1, R6.1
unnamed: J4.2, R7.1
unnamed: J5.2, JP11.3 (B)
unnamed: JP1.2 (C), R1.2
unnamed: JP3.1 (A), R2.1
unnamed: JP4.1 (A), R3.1
unnamed: JP5.2 (B), PS1.7 (RESET)
unnamed: JP6.2 (B), PS1.6 (INT)
unnamed: JP9.2 (B), PS1.5 (DSET)
unnamed: JP10.1 (A), PS1.13 (DOUT)
unnamed: C11.1, JP11.1 (A)
unnamed: JP11.2 (C), PS1.8 (VCAP)
P2110B_DOUT: JP10.2 (B), U1.17 (PA3)
P2110B_DSET: JP9.1 (A), U1.35 (PB14)
P2110B_INT: JP6.1 (A), U1.36 (PB15)
P2110B_RESET: JP5.1 (A), U1.37 (PC6)
PSENSE_MINUS: J6.6, TP1.1, U1.8 (PC0)
PSENSE_PLUS: J6.2, TP2.1, U1.9 (PC1)
SWCLK: J2.2, U1.49 (PA14)
SWDIO: J2.3, U1.46 (PA13)
USART1_RX: R7.2, TP13.1, U1.43 (PA10)
USART1_TX: R6.2, TP11.1, U1.42 (PA9)
VDD: C1.1, C2.1, C3.1, C4.1, C5.1, C6.1, C7.1, J1.4, J6.8, JP1.1 (A), R4.1, S1.2, TP16.1, U1.1 (VBAT), U1.13 (VDDA/VREF+), U1.19 (VDD), U1.32 (VDD), U1.48 (VDD), U1.64 (VDD)

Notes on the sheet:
Reset circuit taken from STM32U031x4/6/8 datasheet pg. 81
Powercast datasheet suggests trace width of 50mils (1.27mm) and spacing between trace and GND of 9mils (0.23mm) for a board thickness of 62mils to ensure 50ohm feedline.
BOOT0 low - boot from main flash memory BOOT0 high - boot from system memory
DSET [digital in] -> enables measurement of harvested power. INT [digital out] -> indicates voltage present at Vout. RESET [digital in] -> set to disable Vout. DOUT [digital out] -> analog voltage level corresponding to harvested power.
nRF24L01 header
Microcontroller
Powercast
Debug and UART header
Mounting holes
Pressure sensor
Power multiplexing

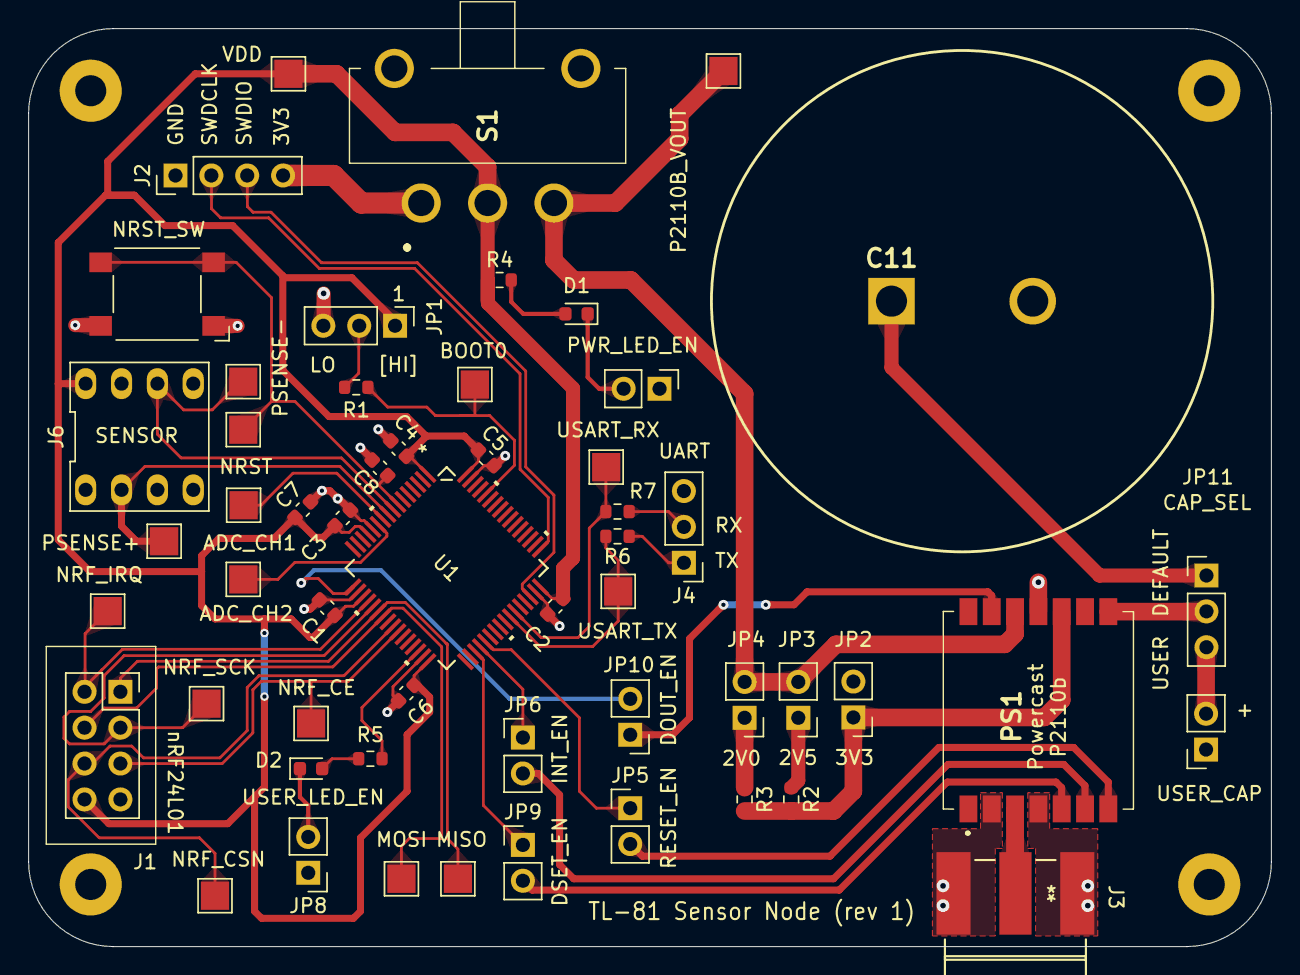
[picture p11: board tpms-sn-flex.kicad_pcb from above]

Board: 2 copper layers, 88.0 x 65.0 mm, 59 parts (0 on the bottom side), 43 nets.

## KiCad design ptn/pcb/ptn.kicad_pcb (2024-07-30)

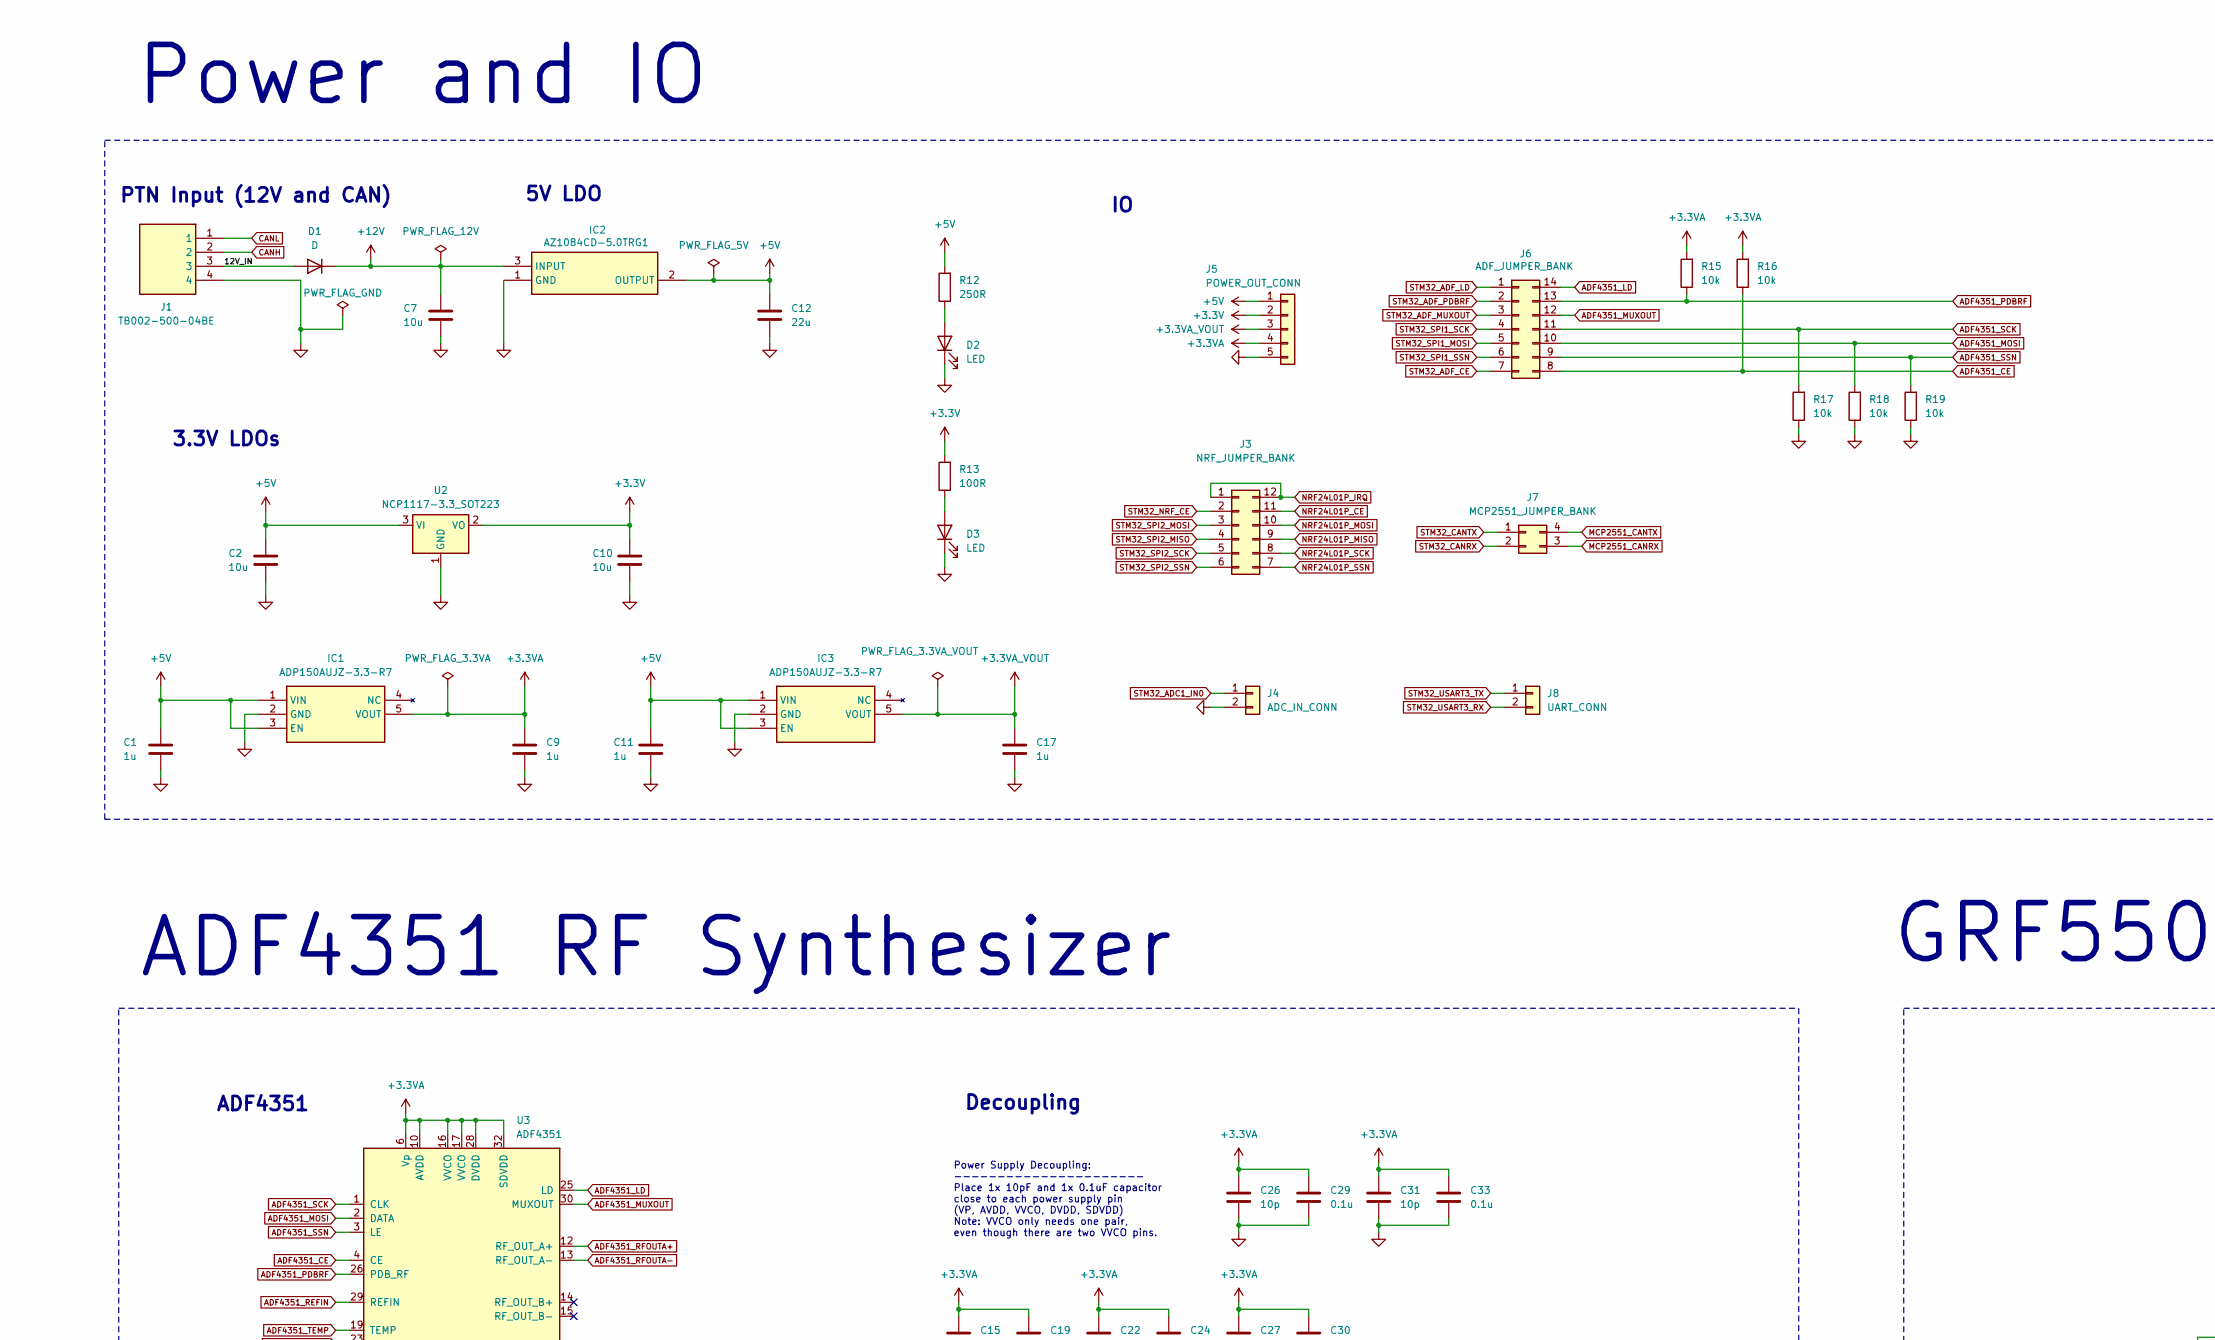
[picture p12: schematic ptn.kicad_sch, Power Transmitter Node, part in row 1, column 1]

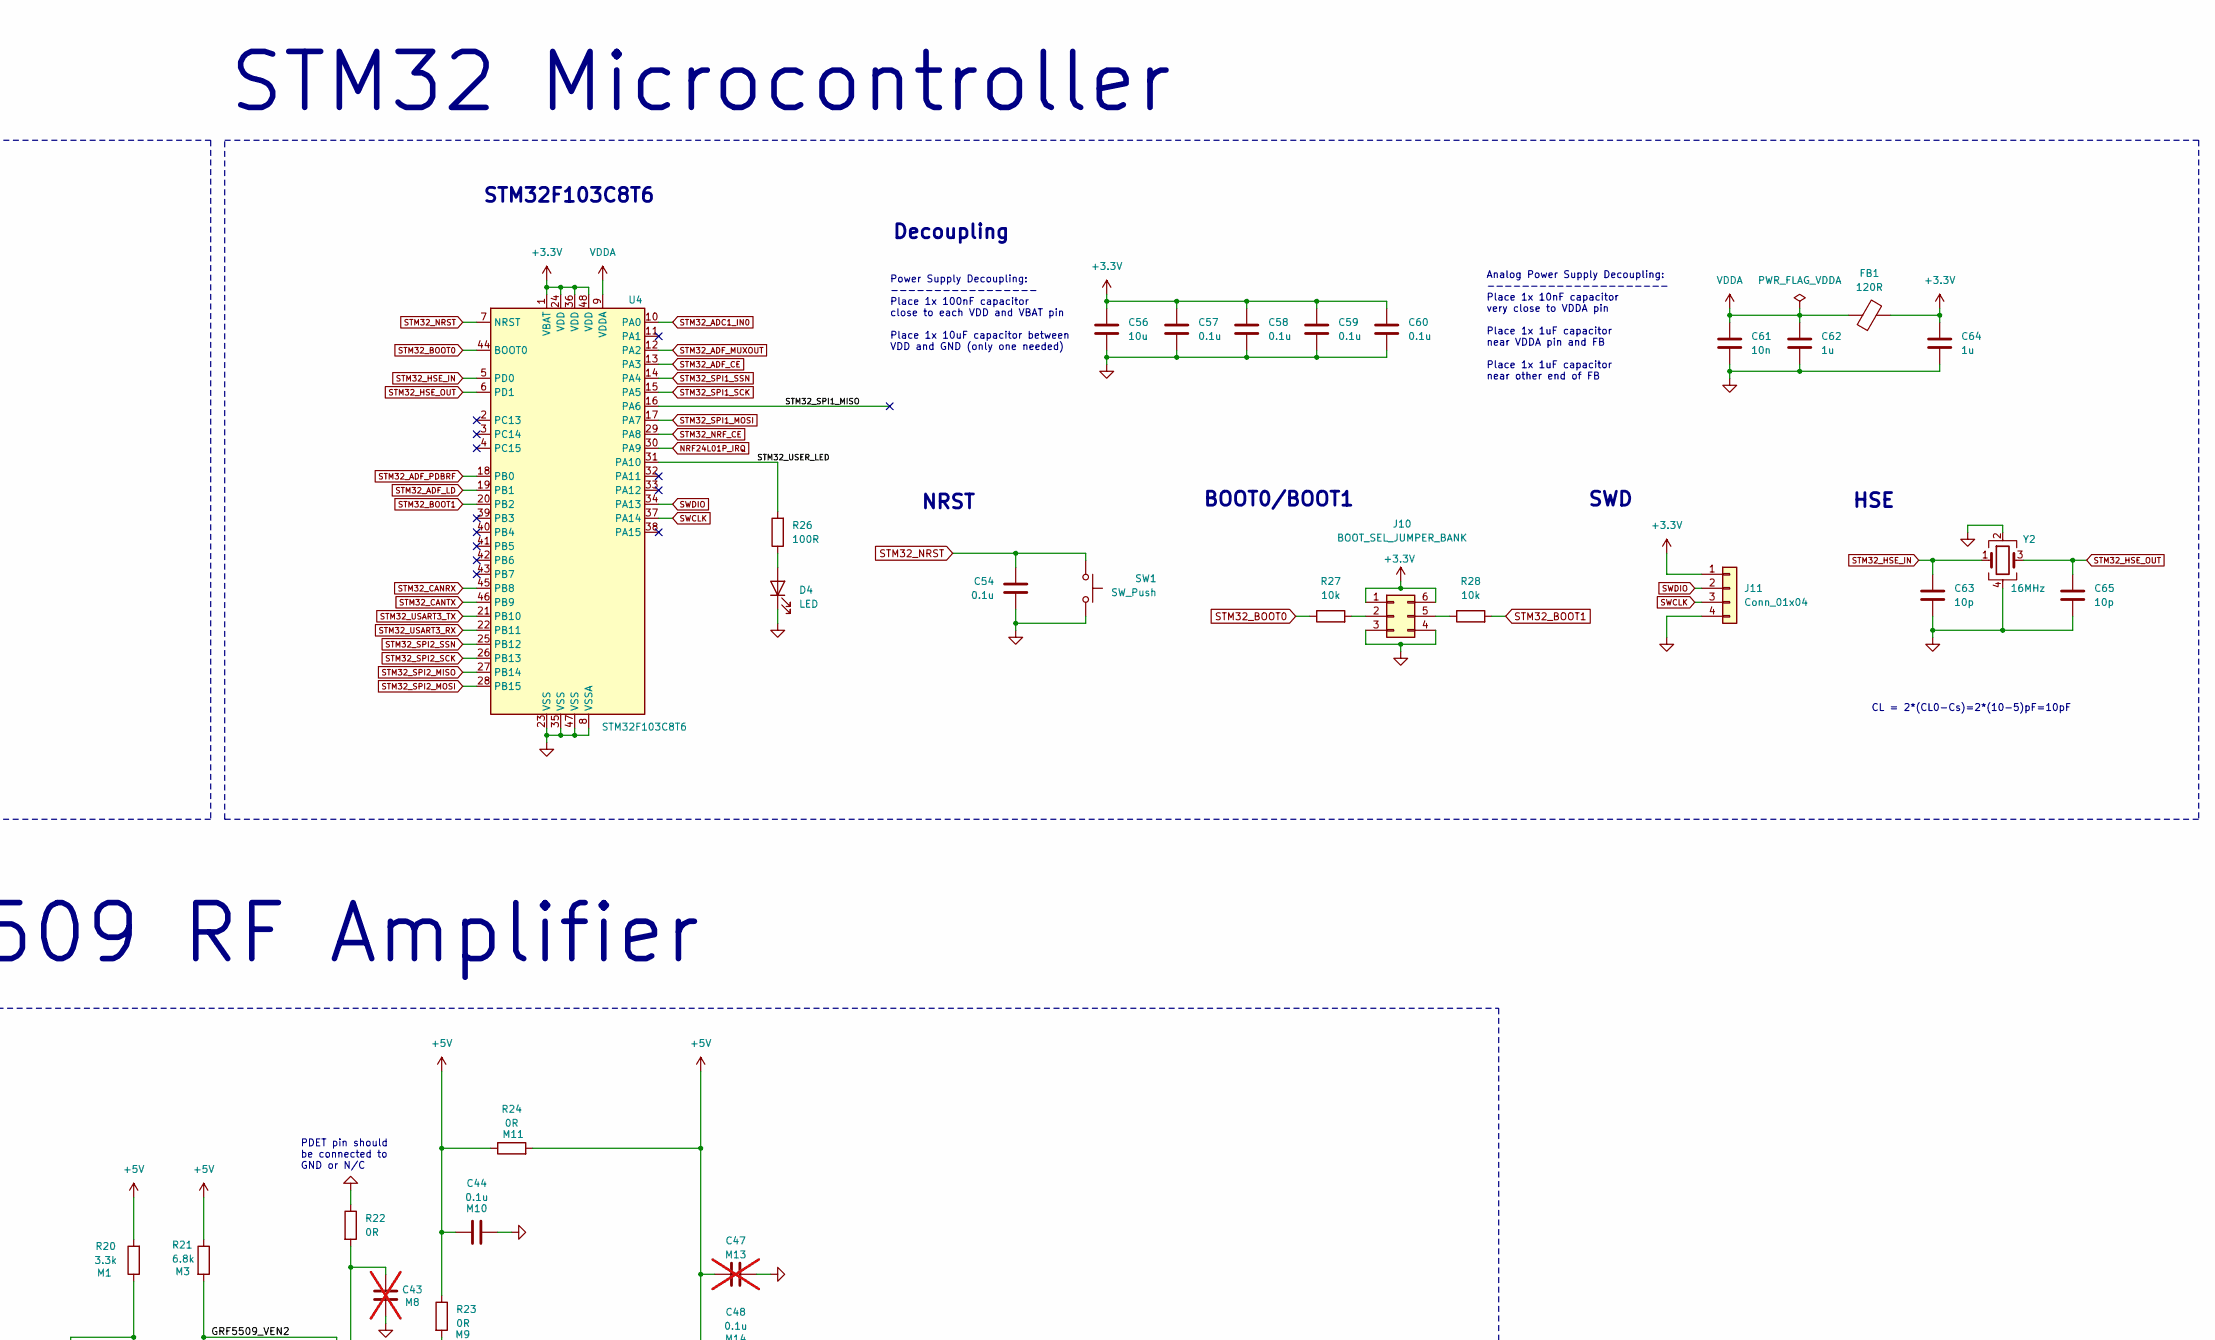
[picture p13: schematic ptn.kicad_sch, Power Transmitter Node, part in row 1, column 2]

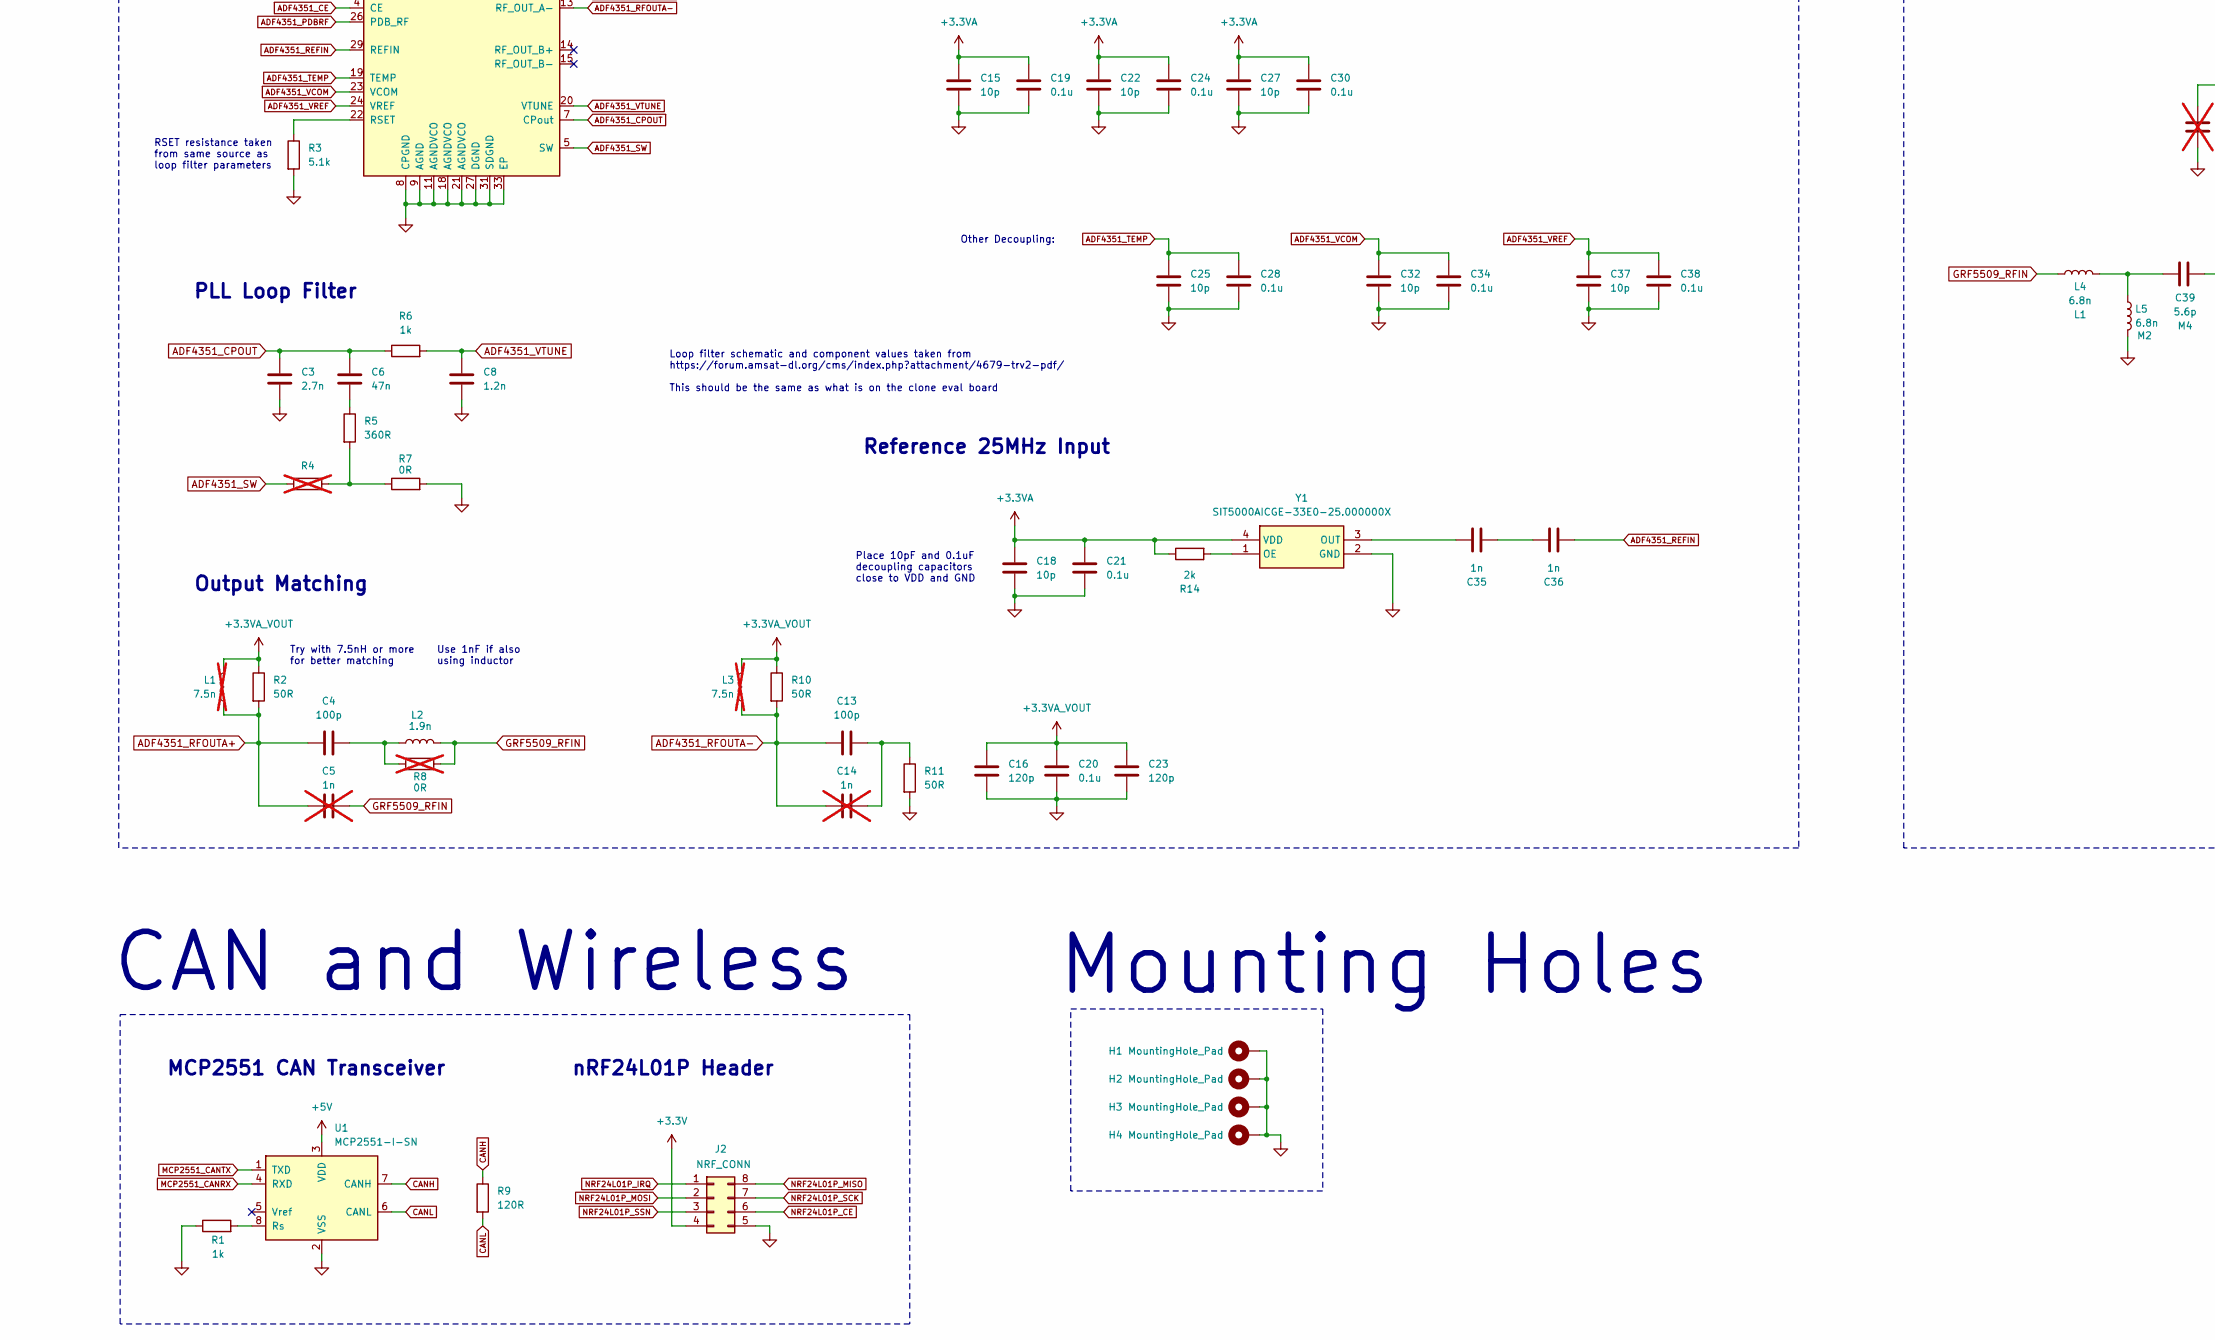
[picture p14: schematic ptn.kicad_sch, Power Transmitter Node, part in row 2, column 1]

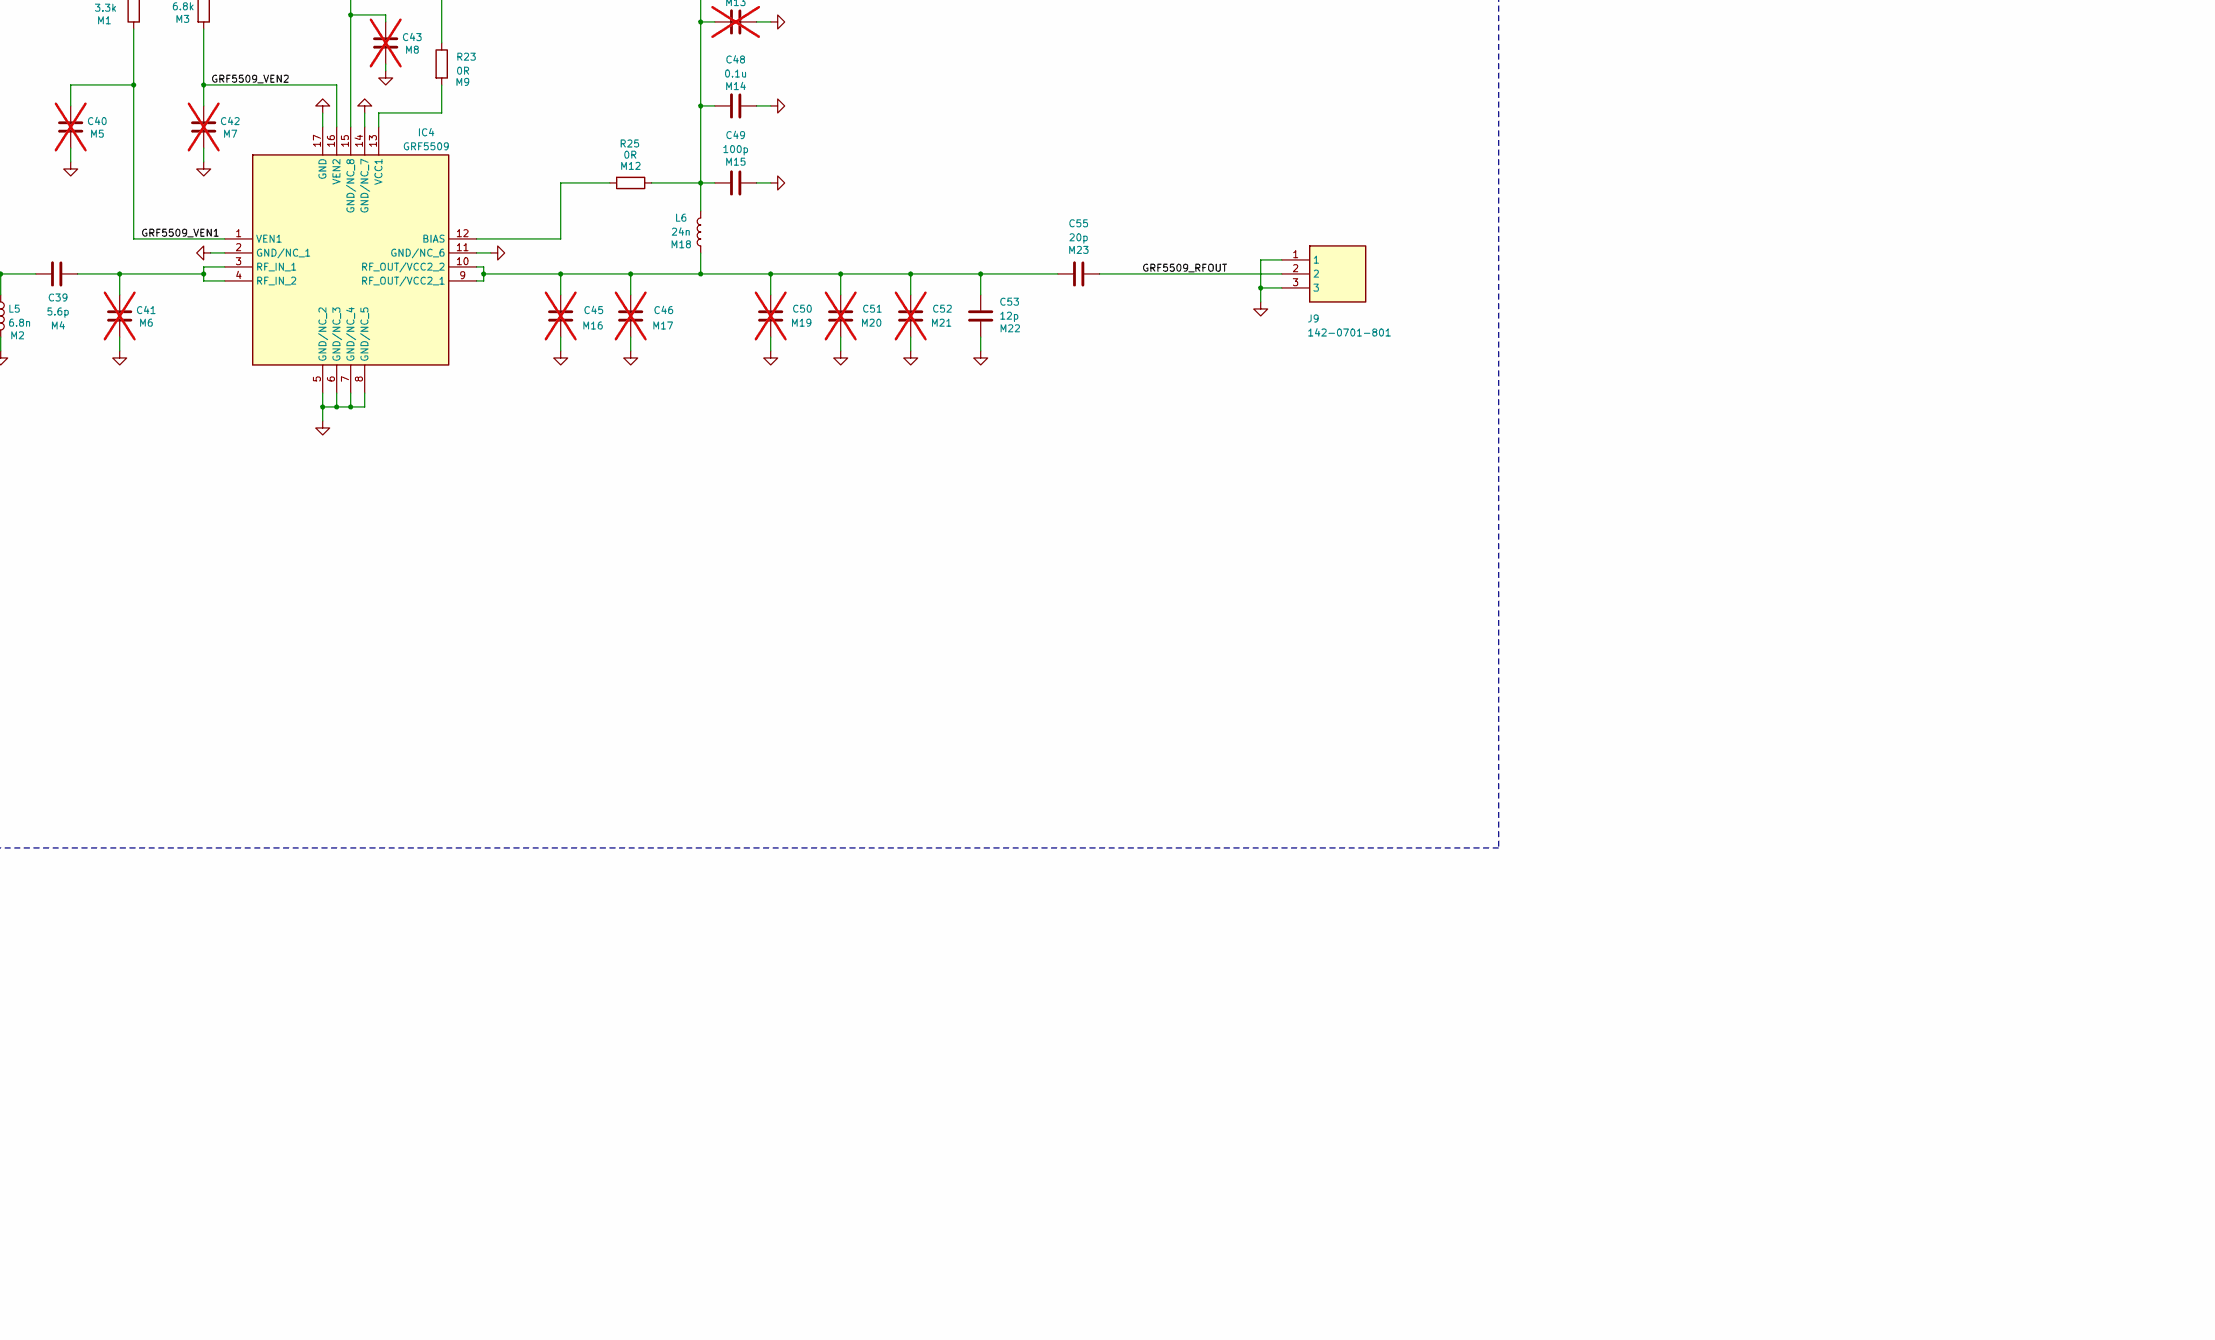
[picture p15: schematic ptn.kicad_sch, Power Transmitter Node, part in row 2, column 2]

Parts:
C1, C9, C11, C17, C62, C64: 1u; C_0603_1608Metric; Manufacturer_Part_Number C0603C105K3PACTU; Mouser Part Number 80-C0603C105K3P
C2, C7, C10, C56: 10u; C_0805_2012Metric; Manufacturer_Part_Number GRM21BR61E106KA73K; Mouser Part Number 81-GRM21BR61E106KA3K
C3: 2.7n; C_0603_1608Metric; Manufacturer_Part_Number 06031C272JAT2A; Mouser Part Number 581-06031C272JAT2A
C4, C13, C49: 100p; C_0402_1005Metric; Manufacturer_Part_Number GRM1555C1H101FA01D; Mouser Part Number 81-GRM1555C1H101FA1D
C5, C14: 1n; C_0402_1005Metric; Manufacturer_Part_Number GRM1555C1H102FA01D; Mouser Part Number 81-GRM1555C1H102FA1D; not fitted
C6: 47n; C_0603_1608Metric; Manufacturer_Part_Number C0603C473J3RACTU; Mouser Part Number 80-C0603C473J3R
C8: 1.2n; C_0603_1608Metric; Manufacturer_Part_Number C0603C122J5RACTU; Mouser Part Number 80-C0603C122J5R
C12: 22u; C_0805_2012Metric; Manufacturer_Part_Number GRM21BR61E226ME44K; Mouser Part Number 81-GRM21BR61E226ME4K
C15, C18, C22, C25, C26, C27, C31, C32, C37, C63, C65: 10p; C_0402_1005Metric; Manufacturer_Part_Number GCM1555C1H100JA16J; Mouser Part Number 81-GCM1555C1H100JA6J
C16, C23: 120p; C_0402_1005Metric; Manufacturer_Part_Number GRM1555C1H121FA01D; Mouser Part Number 81-GRM1555C1H121FA1D
C19, C20, C21, C24, C28, C29, C30, C33, C34, C38, C44, C48, C54, C57, C58, C59, C60: 0.1u; C_0402_1005Metric; Manufacturer_Part_Number GRM155R71C104JA88J; Mouser Part Number 81-GRM155R71C104JA8J
C35, C36: 1n; C_0603_1608Metric; Manufacturer_Part_Number 06035A102JAT2A; Mouser Part Number 581-06035A102J
C39: 5.6p; C_0402_1005Metric; Manufacturer_Part_Number GJM1555C1H5R6WB01D; Mouser Part Number 81-GJM1555C1H5R6WB1D
C40, C41, C42, C43, C45, C46, C47, C50, C51, C52: C_0402_1005Metric; not fitted
C53: 12p; C_0402_1005Metric; Manufacturer_Part_Number GJM1555C1H120FB01D; Mouser Part Number 81-GJM1555C1H120FB1D
C55: 20p; C_0402_1005Metric; Manufacturer_Part_Number GJM1555C1H200FB01D; Mouser Part Number 81-GJM1555C1H200FB1D
C61: 10n; C_0402_1005Metric; Manufacturer_Part_Number C0402C103J8RACTU; Mouser Part Number 80-C0402C103J8RACTU
D1: D; RF302LAM2STR_DIODE; Manufacturer_Part_Number RF302LAM2STR; Mouser Part Number 755-RF302LAM2STR
D2, D3, D4: LED; LED_0603_1608Metric; Manufacturer_Part_Number 150060VS55040; Mouser Part Number 710-150060VS55040
FB1: 120R; L_0603_1608Metric; Manufacturer_Part_Number MFBM1V1608-121-R; Mouser Part Number 704-MFBM1V1608-121-R
H1, H2, H3, H4: MountingHole_Pad; MountingHole_4.3mm_M4_Pad
IC1, IC3: ADP150AUJZ-3.3-R7; SOT95P280X100-5N; Mouser Part Number 584-ADP150AUJZ-3.3R7
IC2: AZ1084CD-5.0TRG1; AZ1084CD50TRG1_LDO_5V; Mouser Part Number 621-AZ1084CD-5.0TRG1
IC4: GRF5509; QFN50P300X300X85-17N; Mouser Part Number 459-GRF5509
J1: TB002-500-04BE; TB00250004BE_SCREW_TERMINAL; Mouser Part Number 490-TB002-500-04BE
J2: NRF_CONN; PinSocket_2x04_P2.54mm_Vertical
J3: NRF_JUMPER_BANK; PinHeader_2x06_P2.54mm_Vertical
J4: ADC_IN_CONN; PinHeader_1x02_P2.54mm_Vertical
J5: POWER_OUT_CONN; PinHeader_1x05_P2.54mm_Vertical
J6: ADF_JUMPER_BANK; PinHeader_2x07_P2.54mm_Vertical
J7: MCP2551_JUMPER_BANK; PinHeader_2x02_P2.54mm_Vertical
J8: UART_CONN; PinHeader_1x02_P2.54mm_Vertical
J9: 142-0701-801; 142-0701-851; Mouser Part Number 530-142-0701-801
J10: BOOT_SEL_JUMPER_BANK; PinHeader_2x03_P2.54mm_Vertical
J11: Conn_01x04; PinHeader_1x04_P2.54mm_Vertical
L1, L3: 7.5n; L_0402_1005Metric; Manufacturer_Part_Number LQW15AN7N5G80D; Mouser Part Number 81-LQW15AN7N5G80D; not fitted
L2: 1.9n; L_0402_1005Metric; Manufacturer_Part_Number LQG15WZ1N9C02D; Mouser Part Number 81-LQG15WZ1N9C02D
L4, L5: 6.8n; L_0402_1005Metric; Manufacturer_Part_Number LQG15WH6N8G02D; Mouser Part Number 81-LQG15WH6N8G02D
L6: 24n; L_0603_1608Metric; Manufacturer_Part_Number LQW18AN24NG80D; Mouser Part Number 81-LQW18AN24NG80D
R1, R6: 1k; R_0603_1608Metric; Manufacturer_Part_Number RC0603FR-101KL; Mouser Part Number 603-RC0603FR-101KL
R2, R10, R11: 50R; R_0402_1005Metric; Manufacturer_Part_Number RC0402JR-0750RL; Mouser Part Number 603-RC0402JR-0750RL
R3: 5.1k; R_0603_1608Metric; Manufacturer_Part_Number CRCW06035K10FKEC; Mouser Part Number 71-CRCW06035K10FKEC
R4: R_0603_1608Metric; not fitted
R5: 360R; R_0603_1608Metric; Manufacturer_Part_Number RT0603DRE07360RL; Mouser Part Number 603-RT0603DRE07360RL
R7: 0R; R_0603_1608Metric; Manufacturer_Part_Number RCS06030000Z0EA; Mouser Part Number 71-RCS06030000Z0EA
R8: 0R; R_0402_1005Metric; Manufacturer_Part_Number RCS04020000Z0ED; Mouser Part Number 71-RCS04020000Z0ED; not fitted
R9: 120R; R_0603_1608Metric; Manufacturer_Part_Number RC0603FR-10120RL; Mouser Part Number 603-RC0603FR-10120RL
R12: 250R; R_0603_1608Metric; Manufacturer_Part_Number RT0603BRE07250RL; Mouser Part Number 603-RT0603BRE07250RL
R13, R26: 100R; R_0603_1608Metric; Manufacturer_Part_Number RT0603DRE07100RL; Mouser Part Number 603-RT0603DRE07100RL
R14: 2k; R_0603_1608Metric; Manufacturer_Part_Number RT0603FRE102KL; Mouser Part Number 603-RT0603FRE102KL
R15, R16, R17, R18, R19, R27, R28: 10k; R_0603_1608Metric; Manufacturer_Part_Number RT0603FRE1310KL; Mouser Part Number 603-RT0603FRE1310KL
R20: 3.3k; R_0402_1005Metric; Manufacturer_Part_Number ERJ-2GEJ332X; Mouser Part Number 667-ERJ-2GEJ332X
R21: 6.8k; R_0402_1005Metric; Manufacturer_Part_Number ERJ-2GEJ682X; Mouser Part Number 667-ERJ-2GEJ682X
R22, R23, R24, R25: 0R; R_0402_1005Metric; Manufacturer_Part_Number RCS04020000Z0ED; Mouser Part Number 71-RCS04020000Z0ED
SW1: SW_Push; SW_SPST_Omron_B3FS-100xP; Manufacturer_Part_Number B3FS-1002P; Mouser Part Number 653-B3FS-1002P
U1: MCP2551-I-SN; SOIC-8_3.9x4.9mm_P1.27mm; Manufacturer_Part_Number MCP2551-I/SN; Mouser Part Number 579-MCP2551-I/SN
U2: NCP1117-3.3_SOT223; SOT-223-3_TabPin2; Manufacturer_Part_Number NCP1117ST33T3G; Mouser Part Number 863-NCP1117ST33T3G
U3: ADF4351; LFCSP-32-1EP_5x5mm_P0.5mm_EP3.25x3.25mm; Manufacturer_Part_Number ADF4351BCPZ-RL7; Mouser Part Number 584-ADF4351BCPZ-R7
U4: STM32F103C8T6; LQFP-48_7x7mm_P0.5mm; Manufacturer_Part_Number STM32F103C8T6; Mouser Part Number 511-STM32F103C8T6
Y1: SIT5000AICGE-33E0-25.000000X; SIT5000AICGE33E025000000X; Mouser Part Number 788-5000AICGE3E0-25X
Y2: 16MHz; 16MHz_830108288709; Manufacturer_Part_Number 830108288709; Mouser Part Number 710-830108288709

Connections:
+3.3V: C10.1, C56.2, C57.2, C58.2, C59.2, C60.2, C64.2, FB1.2, J2.4, J5.2, J10.1, J10.6, J11.1, R13.2, U2.2 (VO), U4.1 (VBAT), U4.24 (VDD), U4.36 (VDD), U4.48 (VDD)
+3.3VA: C9.1, C15.1, C18.1, C19.1, C21.1, C22.1, C24.1, C26.1, C27.1, C29.1, C30.1, C31.1, C33.1, IC1.5 (VOUT), J5.4, R14.1, R15.2, R16.2, U3.6 (Vp), U3.10 (AVDD), U3.16 (VVCO), U3.17 (VVCO), U3.28 (DVDD), U3.32 (SDVDD), Y1.4 (VDD)
+3.3VA_VOUT: C16.1, C17.1, C20.1, C23.1, IC3.5 (VOUT), J5.3, L1.1, L3.1, R2.1, R10.1
+5V: C1.1, C2.1, C11.1, C12.1, C44.2, C47.1, C48.1, C49.1, IC1.1 (VIN), IC1.3 (EN), IC2.2 (OUTPUT), IC3.1 (VIN), IC3.3 (EN), J5.1, L6.2, R12.2, R20.2, R21.1, R23.1, R24.1, R24.2, R25.1, U1.3 (VDD), U2.3 (VI)
+12V: C7.1, D1.1 (K), IC2.3 (INPUT)
/12V_IN: D1.2 (A), J1.3
/GRF5509_RFOUT: C55.2, J9.2
/GRF5509_VEN1: C40.1, IC4.1 (VEN1), R20.1
/GRF5509_VEN2: C42.1, IC4.16 (VEN2), R21.2
/STM32_SPI1_MISO: U4.16 (PA6)
/STM32_USER_LED: R26.2, U4.31 (PA10)
ADF4351_CE: J6.8, R16.1, U3.4 (CE)
ADF4351_CPOUT: C3.1, C6.1, R6.1, U3.7 (CPout)
ADF4351_LD: J6.14, U3.25 (LD)
ADF4351_MOSI: J6.10, R18.2, U3.2 (DATA)
ADF4351_MUXOUT: J6.12, U3.30 (MUXOUT)
ADF4351_PDBRF: J6.13, R15.1, U3.26 (PDB_RF)
ADF4351_REFIN: C36.2, U3.29 (REFIN)
ADF4351_RFOUTA+: C4.1, C5.1, L1.2, R2.2, U3.12 (RF_OUT_A+)
ADF4351_RFOUTA-: C13.1, C14.1, L3.2, R10.2, U3.13 (RF_OUT_A-)
ADF4351_SCK: J6.11, R17.2, U3.1 (CLK)
ADF4351_SSN: J6.9, R19.2, U3.3 (LE)
ADF4351_SW: R4.1, U3.5 (SW)
ADF4351_TEMP: C25.1, C28.1, U3.19 (TEMP)
ADF4351_VCOM: C32.1, C34.1, U3.23 (VCOM)
ADF4351_VREF: C37.1, C38.1, U3.24 (VREF)
ADF4351_VTUNE: C8.1, R6.2, U3.20 (VTUNE)
CANH: J1.2, R9.1, U1.7 (CANH)
CANL: J1.1, R9.2, U1.6 (CANL)
GND: C1.2, C2.2, C3.2, C7.2, C8.2, C9.2, C10.2, C11.2, C12.2, C15.2, C16.2, C17.2, C18.2, C19.2, C20.2, C21.2, C22.2, C23.2, C24.2, C25.2, C26.2, C27.2, C28.2, C29.2, C30.2, C31.2, C32.2, C33.2, C34.2, C37.2, C38.2, C40.2, C41.2, C42.2, C43.2, C44.1, C45.1, C46.1, C47.2, C48.2, C49.2, C50.1, C51.1, C52.1, C53.1, C54.1, C56.1, C57.1, C58.1, C59.1, C60.1, C61.1, C62.1, C63.1, C64.1, C65.1, D2.1 (K), D3.1 (K), D4.1 (K), H1.1, H2.1, H3.1, H4.1, IC1.2 (GND), IC2.1 (GND), IC3.2 (GND), IC4.2 (GND/NC_1), IC4.5 (GND/NC_2), IC4.6 (GND/NC_3), IC4.7 (GND/NC_4), IC4.8 (GND/NC_5), IC4.11 (GND/NC_6), IC4.14 (GND/NC_7), IC4.17 (GND), J1.4, J2.5, J4.2, J5.5, J9.1, J9.3, J10.3, J10.4, J11.4, L5.2, R1.1, R3.2, R7.2, R11.2, R17.1, R18.1, R19.1, R22.1, SW1.1, U1.2 (VSS), U2.1 (GND), U3.8 (CPGND), U3.9 (AGND), U3.11 (AGNDVCO), U3.18 (AGNDVCO), U3.21 (AGNDVCO), U3.27 (DGND), U3.31 (SDGND), U3.33 (EP), U4.8 (VSSA), U4.23 (VSS), U4.35 (VSS), U4.47 (VSS), Y1.2 (GND), Y2.2, Y2.4
GRF5509_RFIN: C5.2, L2.2, L4.1, R8.1
MCP2551_CANRX: J7.3, U1.4 (RXD)
MCP2551_CANTX: J7.4, U1.1 (TXD)
NRF24L01P_CE: J2.6, J3.11
NRF24L01P_IRQ: J2.1, J3.1, J3.12, U4.30 (PA9)
NRF24L01P_MISO: J2.8, J3.9
NRF24L01P_MOSI: J2.2, J3.10
NRF24L01P_SCK: J2.7, J3.8
NRF24L01P_SSN: J2.3, J3.7
unnamed: C4.2, L2.1, R8.2
unnamed: C6.2, R5.1
unnamed: C13.2, C14.2, R11.1
unnamed: C35.2, C36.1
unnamed: C39.1, L4.2, L5.1
unnamed: D2.2 (A), R12.1
unnamed: D3.2 (A), R13.1
unnamed: D4.2 (A), R26.1
unnamed: IC4.12 (BIAS), R25.2
unnamed: C43.1, IC4.15 (GND/NC_8), R22.2
unnamed: C39.2, C41.1, IC4.3 (RF_IN_1), IC4.4 (RF_IN_2)
unnamed: C45.2, C46.2, C50.2, C51.2, C52.2, C53.2, C55.1, IC4.9 (RF_OUT/VCC2_1), IC4.10 (RF_OUT/VCC2_2), L6.1
unnamed: IC4.13 (VCC1), R23.2
unnamed: J10.2, R27.2
unnamed: J10.5, R28.1
unnamed: R4.2, R5.2, R7.1
unnamed: R1.2, U1.8 (Rs)
unnamed: R3.1, U3.22 (RSET)
unnamed: R14.2, Y1.1 (OE)
unnamed: C35.1, Y1.3 (OUT)
STM32_ADC1_IN0: J4.1, U4.10 (PA0)
STM32_ADF_CE: J6.7, U4.13 (PA3)
STM32_ADF_LD: J6.1, U4.19 (PB1)
STM32_ADF_MUXOUT: J6.3, U4.12 (PA2)
STM32_ADF_PDBRF: J6.2, U4.18 (PB0)
STM32_BOOT0: R27.1, U4.44 (BOOT0)
STM32_BOOT1: R28.2, U4.20 (PB2)
STM32_CANRX: J7.2, U4.45 (PB8)
STM32_CANTX: J7.1, U4.46 (PB9)
STM32_HSE_IN: C63.2, U4.5 (PD0), Y2.1
STM32_HSE_OUT: C65.2, U4.6 (PD1), Y2.3
STM32_NRF_CE: J3.2, U4.29 (PA8)
STM32_NRST: C54.2, SW1.2, U4.7 (NRST)
STM32_SPI1_MOSI: J6.5, U4.17 (PA7)
STM32_SPI1_SCK: J6.4, U4.15 (PA5)
STM32_SPI1_SSN: J6.6, U4.14 (PA4)
STM32_SPI2_MISO: J3.4, U4.27 (PB14)
STM32_SPI2_MOSI: J3.3, U4.28 (PB15)
STM32_SPI2_SCK: J3.5, U4.26 (PB13)
STM32_SPI2_SSN: J3.6, U4.25 (PB12)
STM32_USART3_RX: J8.2, U4.22 (PB11)
STM32_USART3_TX: J8.1, U4.21 (PB10)
SWCLK: J11.3, U4.37 (PA14)
SWDIO: J11.2, U4.34 (PA13)
VDDA: C61.2, C62.2, FB1.1, U4.9 (VDDA)

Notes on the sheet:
BOOT0/BOOT1
HSE
Mounting Holes
PDET pin should be connected to GND or N/C
NRST
ADF4351
Decoupling
CAN and Wireless
Power and IO
Other Decoupling:
ADF4351 RF Synthesizer
MCP2551 CAN Transceiver
CL = 2*(CL0-Cs)=2*(10-5)pF=10pF
Try with 7.5nH or more for better matching
Power Supply Decoupling: ----------------- Place 1x 100nF capacitor close to each VDD and VBAT pin Place 1x 10uF capacitor between VDD and GND (only one needed)
GRF5509 RF Amplifier
3.3V LDOs
PTN Input (12V and CAN)
Analog Power Supply Decoupling: --------------------- Place 1x 10nF capacitor very close to VDDA pin Place 1x 1uF capacitor near VDDA pin and FB Place 1x 1uF capacitor near other end of FB
Place 10pF and 0.1uF decoupling capacitors close to VDD and GND
Use 1nF if also using inductor
PLL Loop Filter
RSET resistance taken from same source as loop filter parameters
Power Supply Decoupling: ---------------------- Place 1x 10pF and 1x 0.1uF capacitor close to each power supply pin (VP, AVDD, VVCO, DVDD, SDVDD) Note: VVCO only needs one pair, even though there are two VVCO pins.
STM32 Microcontroller
nRF24L01P Header
Reference 25MHz Input
Output Matching
5V LDO
Loop filter schematic and component values taken from https://forum.amsat-dl.org/cms/index.php?attachment/4679-trv2-pdf/ This should be the same as what is on the clone eval board
STM32F103C8T6
SWD

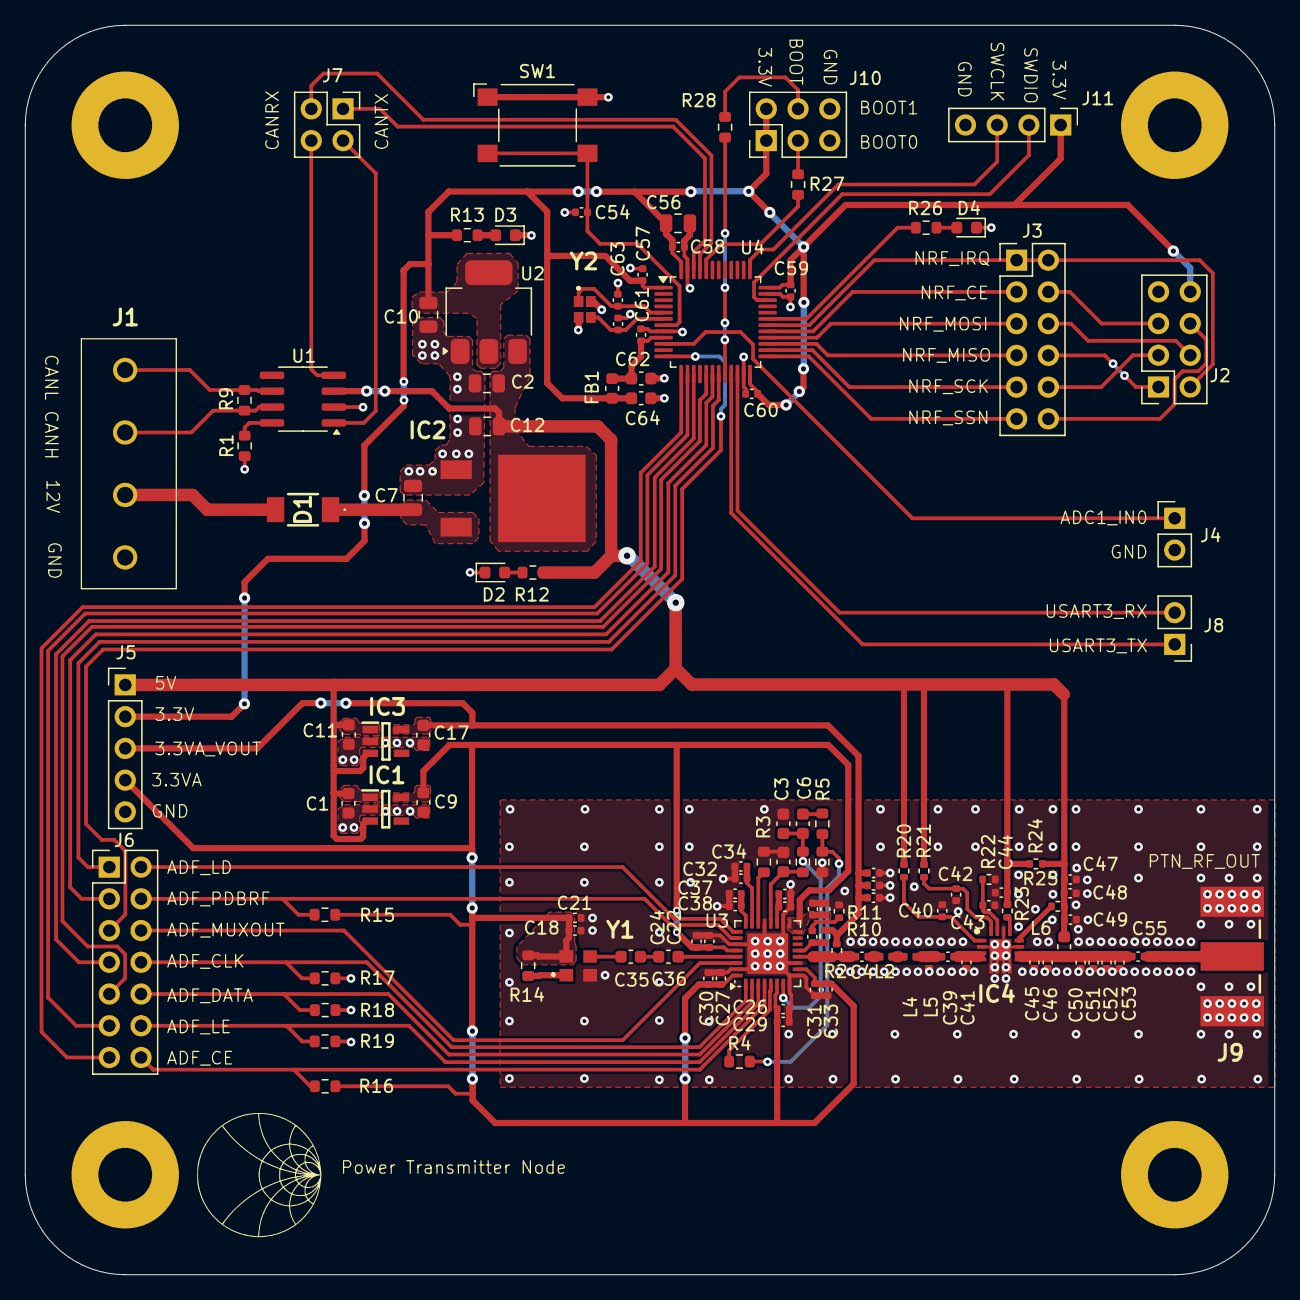
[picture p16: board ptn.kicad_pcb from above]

Board: 2 copper layers, 100.0 x 100.0 mm, 125 parts (0 on the bottom side), 83 nets.

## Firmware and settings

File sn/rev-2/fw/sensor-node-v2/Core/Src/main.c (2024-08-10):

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
/* Includes ------------------------------------------------------------------*/
#include "main.h"
#include "adc.h"
#include "rng.h"
#include "spi.h"
#include "usart.h"
#include "gpio.h"

/* USER CODE BEGIN Includes */

#include "nrf24l01.h"

/* USER CODE END Includes */

/* USER CODE BEGIN PD */

#define TRUE  (1)
#define FALSE (0)

#define BURST_MSG_NUM 3

#define REF_VOLTAGE_MEASUREMENT    (2250)
#define VOLTAGE_PRESSURE_SLOPE_ONE (0.2679)
#define VOLTAGE_PRESSURE_SLOPE_TWO (0.5611)

#define START_DELAY_MS             0
#define STOP_DELAY_MS              0
#define CONSECUTIVE_BURST_DELAY_MS 0
#define SETUP_TO_TX_DELAY_MS       1

#define ADC_TIMEOUT_MS 500

#define POWERCAST_RESET FALSE

/* USER CODE END PD */


void SystemClock_Config(void);
/* USER CODE BEGIN PFP */

void read_back_config(void);
uint16_t process_temp_val(uint32_t raw_val);

/* USER CODE END PFP */

/**
  * @brief  The application entry point.
  * @retval int
  */
int main(void)
{

  /* USER CODE BEGIN 1 */

  uint8_t tx_payload[MAX_DATA_BYTES] = {0};
  uint8_t rf_payload[PAYLOAD_SZ_BYTES] = {0};
  uint8_t rx_buffer[MAX_DATA_BYTES] = {0};

  HAL_StatusTypeDef send_status = HAL_ERROR;
  HAL_StatusTypeDef adc_status = HAL_ERROR;

  /* USER CODE END 1 */

  /* MCU Configuration--------------------------------------------------------*/

  /* Reset of all peripherals, Initializes the Flash interface and the Systick. */
  HAL_Init();

  /* Configure the system clock */
  SystemClock_Config();

  /* Initialize all configured peripherals */
  MX_GPIO_Init();
  MX_ADC1_Init();
  MX_SPI1_Init();
  MX_USART3_UART_Init();
  MX_RNG_Init();
  /* USER CODE BEGIN 2 */

  // make sure RESET signal to power harvester is low
  HAL_GPIO_WritePin(P2110B_RESET_GPIO_Port, P2110B_RESET_Pin, GPIO_PIN_RESET);

  HAL_PWREx_EnableLowPowerRunMode();

  tx_spi_cmd(&hspi1, R_REGISTER(CONFIG_REGISTER), NULL, 0);

  HAL_Delay(START_DELAY_MS);

  // [REQUIRED] make sure to power on the device
  tx_payload[0] = 0b00001110;
  tx_spi_cmd(&hspi1, W_REGISTER(CONFIG_REGISTER), tx_payload, 1);

  // [REQUIRED] set payload size for pipe 0
  tx_payload[0] = PAYLOAD_SZ_BYTES;
  tx_spi_cmd(&hspi1, W_REGISTER(RX_PW_P0), tx_payload, 1);

  // [REQUIRED] set the RF configuration
  NrfRfSetup_t rf_config = {.data_power = ZERO_DBM, .data_rate = TWO_MBPS};
  nrf24l01_setup_rf(&hspi1, &rf_config);

  // [NOT REQUIRED] disable auto-retransmission
  tx_payload[0] = 0x0;
  tx_spi_cmd(&hspi1, W_REGISTER(SETUP_RETR), tx_payload, 1);

  // tx_payload[0] = 0x3;
  // tx_spi_cmd(W_REGISTER(SETUP_RETR), tx_payload, 1);

  // [REQUIRED] enable `W_TX_PAYLOAD_NOACK` command
  tx_payload[0] = 0x1;
  tx_spi_cmd(&hspi1, W_REGISTER(FEATURE), tx_payload, 1);

  // [NOT REQUIRED] flush the TX buffer
  tx_spi_cmd(&hspi1, FLUSH_TX, NULL, 0);

  // required when MCU clock speed is more than or equal to 24MHz
  HAL_Delay(STOP_DELAY_MS);

  HAL_ADC_Start(&hadc1);

  // measure the pressure using the ADC
  adc_status = HAL_ADC_PollForConversion(&hadc1, ADC_TIMEOUT_MS);
  uint32_t pressure_val = HAL_ADC_GetValue(&hadc1);

#if (SENSOR_NODE_ID == SENSOR_NODE_ID_ONE)
  double pressure_val_proc =
      (REF_VOLTAGE_MEASUREMENT - (pressure_val & 0xffff)) *
      VOLTAGE_PRESSURE_SLOPE_ONE;
#else
  // NOTE: reference voltage looks to be around 2250.
  double pressure_val_proc =
      (REF_VOLTAGE_MEASUREMENT - (pressure_val & 0xffff)) *
      VOLTAGE_PRESSURE_SLOPE_TWO;
#endif

  uint16_t pressure_val_final = (uint16_t)(pressure_val_proc);

  HAL_ADC_Stop(&hadc1);

  // generate random number so that each burst message has an ID
  uint32_t random_id = 0;
  HAL_RNG_GenerateRandomNumber(&hrng, &random_id);

  int16_t temperature = 22;

  if (random_id > (0xffffffff >> 1)) {
    temperature++;
  }

  sensor_msg_t message = {.node_id = SENSOR_NODE_ID,
                          .pressure = pressure_val_final,
                          .temperature = temperature,
                          .msg_id = random_id};

  // copy message into buffer
  memcpy((void *)rf_payload, (void *)(&message), PAYLOAD_SZ_BYTES);

  // send burst of RF messages
  for (int i = 0; i < BURST_MSG_NUM; i++) {
    send_status = nrf24l01_send_msg_noack(&hspi1, rf_payload, PAYLOAD_SZ_BYTES);
    HAL_Delay(CONSECUTIVE_BURST_DELAY_MS);
  }

  HAL_Delay(SETUP_TO_TX_DELAY_MS);

  // reset the power harvester so we don't consume all the stored power
#if (POWERCAST_RESET)
  HAL_GPIO_WritePin(P2110B_RESET_GPIO_Port, P2110B_RESET_Pin, GPIO_PIN_SET);
#endif

  /* USER CODE END 2 */

  /* Infinite loop */
  /* USER CODE BEGIN WHILE */
  while (1) {
    /* USER CODE END WHILE */

    /* USER CODE BEGIN 3 */
  }
  /* USER CODE END 3 */
}

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
/* USER CODE BEGIN 4 */

uint16_t process_temp_val(uint32_t raw_val)
{
  uint16_t cal1_val = *TEMPSENSOR_CAL1_ADDR;
  uint16_t cal2_val = *TEMPSENSOR_CAL2_ADDR;

  double slope = (double)(cal2_val - cal1_val) / (double)(TEMPSENSOR_CAL2_TEMP - TEMPSENSOR_CAL1_TEMP);
  double intercept = TEMPSENSOR_CAL1_TEMP - (slope * cal1_val);

  return (uint16_t)(slope * raw_val + intercept);
}

void read_back_config(void) {
  uint8_t rx_buffer[RX_BUF_SZ_BYTES] = {0};

  tx_rx_spi_cmd(&hspi1, R_REGISTER(CONFIG_REGISTER), NULL, 0, rx_buffer, 1);
  uint8_t config = rx_buffer[0];
  memset(&rx_buffer, 0, sizeof(rx_buffer));

  tx_rx_spi_cmd(&hspi1, R_REGISTER(EN_RXADDR), NULL, 0, rx_buffer, 1);
  uint8_t endp = rx_buffer[0];
  memset(&rx_buffer, 0, sizeof(rx_buffer));

  tx_rx_spi_cmd(&hspi1, R_REGISTER(SETUP_RETR), NULL, 0, rx_buffer, 1);
  uint8_t setup_retr = rx_buffer[0];
  memset(&rx_buffer, 0, sizeof(rx_buffer));

  tx_rx_spi_cmd(&hspi1, R_REGISTER(RF_CH), NULL, 0, rx_buffer, 1);
  uint8_t rfch = rx_buffer[0];
  memset(&rx_buffer, 0, sizeof(rx_buffer));

  tx_rx_spi_cmd(&hspi1, R_REGISTER(RF_SETUP), NULL, 0, rx_buffer, 1);
  uint8_t rfsetup = rx_buffer[0];
  memset(&rx_buffer, 0, sizeof(rx_buffer));

  tx_rx_spi_cmd(&hspi1, R_REGISTER(RX_ADDR_P0), NULL, 0, rx_buffer, 5);
  uint32_t rx_addr_p0_hi = *((uint32_t *)rx_buffer);
  uint32_t rx_addr_p0_lo = *((uint32_t *)rx_buffer + 1);
  memset(&rx_buffer, 0, sizeof(rx_buffer));

  tx_rx_spi_cmd(&hspi1, R_REGISTER(TX_ADDR), NULL, 0, rx_buffer, 5);
  uint32_t tx_addr_hi = *((uint32_t *)rx_buffer);
  uint32_t tx_addr_lo = *((uint32_t *)rx_buffer + 1);
  memset(&rx_buffer, 0, sizeof(rx_buffer));

  tx_rx_spi_cmd(&hspi1, R_REGISTER(RX_PW_P0), NULL, 0, rx_buffer, 5);
  uint8_t rx_pw_p0 = rx_buffer[0];
  memset(&rx_buffer, 0, sizeof(rx_buffer));

  tx_rx_spi_cmd(&hspi1, R_REGISTER(FEATURE), NULL, 0, rx_buffer, 1);
  uint8_t feature = rx_buffer[0];
  memset(&rx_buffer, 0, sizeof(rx_buffer));
}

/* USER CODE END 4 */
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


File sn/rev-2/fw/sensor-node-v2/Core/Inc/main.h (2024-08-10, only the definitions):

#define USER_LED_Pin GPIO_PIN_15
#define USER_LED_GPIO_Port GPIOC
#define PSENSE_OUT_Pin GPIO_PIN_0
#define PSENSE_OUT_GPIO_Port GPIOA
#define PSENSE_VREF_Pin GPIO_PIN_1
#define PSENSE_VREF_GPIO_Port GPIOA
#define PSENSE_MINUS_Pin GPIO_PIN_3
#define PSENSE_MINUS_GPIO_Port GPIOA
#define PSENSE_PLUS_Pin GPIO_PIN_4
#define PSENSE_PLUS_GPIO_Port GPIOA
#define P2110B_DOUT_Pin GPIO_PIN_6
#define P2110B_DOUT_GPIO_Port GPIOA
#define P2110B_DSET_Pin GPIO_PIN_9
#define P2110B_DSET_GPIO_Port GPIOA
#define P2110B_INT_Pin GPIO_PIN_10
#define P2110B_INT_GPIO_Port GPIOA
#define P2110B_RESET_Pin GPIO_PIN_11
#define P2110B_RESET_GPIO_Port GPIOA
#define NRF_IRQ_Pin GPIO_PIN_15
#define NRF_IRQ_GPIO_Port GPIOA
#define NRF_SCK_Pin GPIO_PIN_3
#define NRF_SCK_GPIO_Port GPIOB
#define NRF_MISO_Pin GPIO_PIN_4
#define NRF_MISO_GPIO_Port GPIOB
#define NRF_MOSI_Pin GPIO_PIN_5
#define NRF_MOSI_GPIO_Port GPIOB
#define NRF_CSN_Pin GPIO_PIN_6
#define NRF_CSN_GPIO_Port GPIOB
#define NRF_CE_Pin GPIO_PIN_7
#define NRF_CE_GPIO_Port GPIOB
#define SENSOR_NODE_ID SENSOR_NODE_ID_ONE
#define SENSOR_NODE_ID SENSOR_NODE_ID_TWO

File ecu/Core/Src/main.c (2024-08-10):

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
/* Includes ------------------------------------------------------------------*/
#include "main.h"
#include "can.h"
#include "gpio.h"
#include "stm32f1xx_hal_gpio.h"
#include "usart.h"

/* USER CODE BEGIN Includes */

#include <stdio.h>

/* USER CODE END Includes */

/* USER CODE BEGIN PD */

// Amount of time to keep trying to send a PTN_REQUEST message.
#define PTN_REQUEST_TIMEOUT_MS (1000)


// Amount of time to keep trying to send a PTN_RESET message.
#define PTN_RESET_TIMEOUT_MS (3000)

// Amount of time between consecutive PTN_RESET messages to different PTNs.
#define CONSECUTIVE_RESET_MSG_DELAY_MS (50)

#define UART_TIMEOUT_MS (200)

#define CAN_TX_TO_RX_DELAY_MS (1000)

// Amount of time between attempting consecutive PTN read.
#define PTN_READ_DELAY_MS (5000)

// WARNING: ensure this is between 5000ms (5s) and 15000ms (15s)
#define PTN_ON_TIMEOUT ((uint16_t)15000)

// Amount of time to poll for a CAN message response from a PTN.
#define PTN_RESPONSE_TIMEOUT_MS (PTN_ON_TIMEOUT + (uint16_t)2000)

/* USER CODE END PD */


void SystemClock_Config(void);
/* USER CODE BEGIN PFP */

void print_ecu_state(EcuState_e state);

/* USER CODE END PFP */

/* USER CODE BEGIN 0 */

const CAN_TxHeaderTypeDef req_header = {
    .StdId = PTN_REQUEST_ID,
    .ExtId = 0x0000,
    .IDE = CAN_ID_STD,
    .RTR = CAN_RTR_DATA,
    .DLC = CAN_MSG_FRAME_LEN_BYTES,
    .TransmitGlobalTime = DISABLE,
};

const CAN_TxHeaderTypeDef reset_header = {
    .StdId = PTN_RESET_ID,
    .ExtId = 0x0000,
    .IDE = CAN_ID_STD,
    .RTR = CAN_RTR_DATA,
    .DLC = CAN_MSG_FRAME_LEN_BYTES,
    .TransmitGlobalTime = DISABLE,
};

const uint8_t ptn_list[NUM_PTNS] = {0x1, 0x2};

/* USER CODE END 0 */

/**
 * @brief  The application entry point.
 * @retval int
 */
int main(void) {

  /* USER CODE BEGIN 1 */

  HAL_StatusTypeDef status = HAL_OK;
  EcuState_e ecu_state = ECU_RESET;

  AllPtnState_t all_ptns_state = {0};

  /* USER CODE END 1 */

  /* MCU Configuration--------------------------------------------------------*/

  /* Reset of all peripherals, Initializes the Flash interface and the Systick.
   */
  HAL_Init();

  /* Configure the system clock */
  SystemClock_Config();

  /* Initialize all configured peripherals */
  MX_GPIO_Init();
  MX_CAN_Init();
  MX_USART1_UART_Init();
  /* USER CODE BEGIN 2 */

  printf("log,info,ECU resetting!\r\n");

  // send the RESET message to the GUI
  printf("reset,reset,reset\r\n");

  // delay between the reset message and actually starting to send CAN messages
  // to PTNs
  HAL_Delay(5000);

  // send another RESET message to the GUI
  printf("reset,reset,reset\r\n");

  print_ecu_state(ecu_state);

  HAL_Delay(2500);

  setvbuf(stdout, NULL, _IONBF, 0);

  CAN_FilterTypeDef can_filter = {
      .FilterIdHigh = (uint32_t)(PTN_RESPONSE_ID << 5 | 0x0000),
      .FilterIdLow = 0,
      .FilterMaskIdHigh = 0,
      .FilterMaskIdLow = 0,
      .FilterFIFOAssignment = CAN_FILTER_FIFO0,
      .FilterBank = 0,
      .FilterMode = CAN_FILTERMODE_IDLIST,
      .FilterScale = CAN_FILTERSCALE_32BIT,
      .FilterActivation = CAN_FILTER_ENABLE,
      .SlaveStartFilterBank = 0,
  };

  status |= HAL_CAN_ConfigFilter(&hcan, &can_filter);
  status |= HAL_CAN_Start(&hcan);

  uint8_t can_tx_payload[CAN_MSG_FRAME_LEN_BYTES] = {0};
  uint8_t can_rx_payload[CAN_MSG_FRAME_LEN_BYTES] = {0};
  uint32_t mailbox = 0;
  CAN_RxHeaderTypeDef rx_header = {0};

  uint8_t uart_msg[256] = {0};

  ecu_state = ECU_AUTOLOCALIZATION;
  print_ecu_state(ecu_state);

  for (uint8_t idx = 0; idx < NUM_PTNS; idx++) {
    uint8_t cur_ptn_id = ptn_list[idx];

    printf("Attempting to send PTN_RESET CAN message (ID=0x%x) to PTN ID = "
           "0x%x...\r\n",
           reset_header.StdId, cur_ptn_id);

    status = HAL_CAN_AddTxMessagePolling(&hcan, &reset_header, can_tx_payload,
                                         &mailbox, PTN_RESET_TIMEOUT_MS);

    switch (status) {
    case HAL_OK: {
      printf("[PTN: 0x%x]: HAL_OK, successfully transmitted CAN message "
             "(ID=0x%x) to PTN ID = 0x%x\r\n",
             cur_ptn_id, reset_header.StdId, cur_ptn_id);
      break;
    }
    case HAL_TIMEOUT: {
      printf("[PTN: 0x%x]: status HAL_TIMEOUT (0x%x) returned when trying to "
             "send CAN message (ID=0x%x)!\r\n",
             cur_ptn_id, status, reset_header.StdId);
      break;
    }

    case HAL_ERROR: {
      printf("[PTN: 0x%x]: status HAL_ERROR (0x%x) returned when trying to "
             "send CAN message (ID=0x%x)!\r\n",
             cur_ptn_id, status, reset_header.StdId);
      break;
    }

    case HAL_BUSY: {
      printf("[PTN: 0x%x]: status HAL_BUSY (0x%x) returned when trying to "
             "send CAN message (ID=0x%x)!\r\n",
             cur_ptn_id, status, reset_header.StdId);
      break;
    }

    default: {
      printf("[PTN: 0x%x]: unexpected HAL status (0x%x) returned when trying "
             "to send CAN message (ID=0x%x)!\r\n",
             cur_ptn_id, status, reset_header.StdId);
      break;
    }
    }

    HAL_Delay(CONSECUTIVE_RESET_MSG_DELAY_MS);
  }

  printf("log,info,Finished initialization!\r\n");

  // On reset, ECU must:
  // 1) Send a RESET message to the PTNs
  // 2) Periodically send a request message.
  // 2) Wait for a timeout or a response message.
  // 3) If timeout move on.

  /* USER CODE END 2 */

  /* Infinite loop */
  /* USER CODE BEGIN WHILE */
  while (1) {
    /* USER CODE END WHILE */

    /* USER CODE BEGIN 3 */

    for (uint8_t idx = 0; idx < NUM_PTNS; idx++) {
      uint8_t cur_ptn_id = ptn_list[idx];

      printf("Attempting to send PTN_REQUEST CAN message (ID=0x%x) to PTN ID = "
             "0x%x...\r\n",
             req_header.StdId, cur_ptn_id);

      // byte 0 is the target PTN ID
      can_tx_payload[0] = cur_ptn_id;

      // byte 1 is left empty

      // byte 2-3 is the timeout value in milliseconds
      *((uint16_t *)(can_tx_payload) + 1) = PTN_ON_TIMEOUT;

      printf("[PTN: 0x%x] Setting the PTN with timeout = %d ms\r\n", cur_ptn_id, PTN_ON_TIMEOUT);

      // TODO: add a CAN Rx Fifo flush here

      status = HAL_CAN_AddTxMessagePolling(&hcan, &req_header, can_tx_payload,
                                           &mailbox, PTN_REQUEST_TIMEOUT_MS);

      // if the CAN message doesn't transmit correctly, continue to sending
      // message for next PTN...
      if (status == HAL_OK) {
        printf("[PTN: 0x%x] Successfully transmitted CAN message with ID = "
               "0x%x!\r\n",
               cur_ptn_id, req_header.StdId);
      } else if (status == HAL_TIMEOUT) {
        printf("[PTN: 0x%x] Failed to transmit CAN message with ID = 0x%x due "
               "to timeout!\r\n",
               cur_ptn_id, req_header.StdId);
        continue;
      } else {
        printf("[PTN: 0x%x] Failed to transmit CAN message with ID = 0x%x, "
               "HAL_STATUS = "
               "%d!\r\n",
               cur_ptn_id, req_header.StdId, status);
        continue;
      }
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

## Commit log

2024-05-07 Add antenna validation simulation that works
2024-06-04 Add initial sensor node KiCAD schematic
    [tpms-sn-flex.kicad_pcb, tpms-sn-flex.kicad_sch]
2024-06-06 Add layout and routing for sensor node PCB rev 1
    [tpms-sn-flex.kicad_pcb, tpms-sn-flex.kicad_sch]
2024-06-07 Update PCB with silkscreen and fix DRC violations
    [tpms-sn-flex.kicad_pcb, tpms-sn-flex.kicad_sch]
2024-06-07 Fix decoupling caps to be 0603 footprint
    [tpms-sn-flex.kicad_pcb, tpms-sn-flex.kicad_sch]
2024-06-07 Add manufacturing files for rev 1
    [tpms-sn-flex-B_Cu.gbr, tpms-sn-flex-B_Mask.gbr, tpms-sn-flex-Edge_Cuts.gbr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]
2024-06-12 Add milestone 3 sensor node FW
2024-06-27 Add a delay between sending the nRF the SPI transmission command and sending the Powercast the RESET signal
    [main.c]
2024-07-06 Add PCB footprints
    [206-124.SchLib, 206124.PcbLib, 206124.psm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]
2024-07-06 Reorganize folders
    [tpms-sn-flex-B_Cu.gbr, tpms-sn-flex-B_Mask.gbr, tpms-sn-flex-Edge_Cuts.gbr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]
2024-07-06 Add sensor node rev 2 PCB
    [sensor-node-rev-2-B_Cu.gbr, sensor-node-rev-2-B_Mask.gbr, sensor-node-rev-2-Edge_Cuts.gbr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]
2024-07-09 Use new microcontroller package and remove some jumpers
    [sensor-node-rev-2.kicad_pcb, sensor-node-rev-2.kicad_sch]
2024-07-13 Finish routing and layout for sensor node rev 2
    [sensor-node-rev-2.kicad_pcb, sensor-node-rev-2.kicad_sch]
2024-07-14 Update STM32 footprints
    [QFN50P500X500X60-33N-D.PcbLib, STM32U031K8U6.SchLib]
2024-07-14 Finalize rev 2 for manufacturing
    [sensor-node-rev-2.kicad_pcb]
2024-07-14 Remove lock file
    [tpms-sn-flex.kicad_pcb]
2024-07-14 Add variant of rev 2 board
    [sensor-node-rev-2s-B_Cu.gbr, sensor-node-rev-2s-B_Mask.gbr, sensor-node-rev-2s-Edge_Cuts.gbr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]
2024-07-15 Add footprint and back silkscreen
    [sensor-node-rev-2.csv, sensor-node-rev-2.kicad_pcb, sensor-node-rev-2.kicad_sch]
2024-07-16 Add BOM and initial manufacturing files
    [sensor-node-rev-2-B_Cu.gbr, sensor-node-rev-2-B_Mask.gbr, sensor-node-rev-2-B_Paste.gbr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]
2024-07-16 Add initial manufacturing files for sensor node rev 2s
    [sensor-node-rev-2s-B_Cu.gbr, sensor-node-rev-2s-B_Mask.gbr, sensor-node-rev-2s-B_Paste.gbr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]
2024-07-16 Add little guy on back silkscreen and update manufacturing files
    [sensor-node-rev-2-B_Cu.gbr, sensor-node-rev-2-B_Mask.gbr, sensor-node-rev-2-B_Paste.gbr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]
2024-07-16 Add little guy and update manufacturing files for rev 2s
    [sensor-node-rev-2s-B_Cu.gbr, sensor-node-rev-2s-B_Mask.gbr, sensor-node-rev-2s-B_Paste.gbr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]
2024-07-16 Update BOM with better tolerance capacitor
    [sensor-node-rev-2.csv, sensor-node-rev-2.kicad_sch]
2024-07-16 Fix mistake in BOM
    [sensor-node-rev-2.csv]
2024-07-16 Update manufacturing files and BOM to account for different SMA connector
    [sensor-node-rev-2-B_Cu.gbr, sensor-node-rev-2-B_Mask.gbr, sensor-node-rev-2-B_Paste.gbr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]
2024-07-16 Update silkscreen and manu files for rev 2
    [sensor-node-rev-2-B_Cu.gbr, sensor-node-rev-2-B_Mask.gbr, sensor-node-rev-2-B_Paste.gbr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]
2024-07-16 Update silkscreen and manu files for rev 2s
    [sensor-node-rev-2s-B_Cu.gbr, sensor-node-rev-2s-B_Mask.gbr, sensor-node-rev-2s-B_Paste.gbr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]
2024-07-23 Reorganize PCB projects and FW
    [206-124.SchLib, 206124.PcbLib, 206124.psm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]
2024-07-23 Update sensor node rev 2s PCB and manufacturing files
    [sensor-node-rev-2s-B_Cu.gbr, sensor-node-rev-2s-B_Mask.gbr, sensor-node-rev-2s-B_Paste.gbr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]
2024-07-23 Update sensor node rev 2 PCB and manufacturing files
    [sensor-node-rev-2-B_Cu.gbr, sensor-node-rev-2-B_Mask.gbr, sensor-node-rev-2-B_Paste.gbr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]
2024-07-23 Add more SN footprints
    [142-0701-801.stp, 142-0701-851.psm, 901-10309.stp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]
2024-07-23 Rename sn rev folders
    [sensor-node-rev-2-B_Cu.gbr, sensor-node-rev-2-B_Mask.gbr, sensor-node-rev-2-B_Paste.gbr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]
2024-07-23 Add sensor node rev 2 fw project
2024-07-23 Add schematic PDF for sensor node rev-2
2024-07-25 Update sensor-node-v2 fw to work with CMake
2024-07-25 Add working implementation of sensor-node-v2 firmware
2024-07-25 Update KiCad files
    [sensor-node-rev-2.kicad_pcb]
2024-07-25 Remove flashing LED
2024-07-25 Add POWERCAST_RESET macro
2024-07-30 Add heat map used in M3
    [Tire Bench Path Loss M3 - SN Antenna.csv]
2024-07-30 Add PTN PCB and firmware
    [bom.csv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]
2024-07-30 Add nrf drivers to ptn, start ptn control
2024-07-30 Update receiver code to unpack sensor message correctly
    [main.h]
2024-07-31 Enable setting sensor node ID through Justfile and add sensor node message struct
2024-07-31 Fix struct field names
    [main.c]
2024-07-31 Add initial code for CAN filtering
2024-07-31 Enable UART for ECU
2024-08-01 Modify nRF24L01+ driver to take SPI handle
2024-08-01 Update formatting and improve comments for nRF24L01+ driver
2024-08-02 Add CAN communication (still buggy)
    [main.c, main.h, ptn.ioc]
2024-08-02 Fix CAN message edge case and add ptn_sn_paired as CAN signal
    [main.c, main.h]
2024-08-04 Fix grid issues and make contents stretch to grid container
    [main.py]
2024-08-04 Add tire label textboxes and current time thread
2024-08-04 Fix out-of-sync CAN message bug on ECU
    [can.c, main.c, main.h]
2024-08-04 Add last updated time fields and threads to update them
2024-08-06 Modify ADC pressure measurements to measure air pressure
2024-08-06 Add temperature conversion function
2024-08-07 Add ECU firmware to keep track of ECU state and output state to GUI
2024-08-07 Remove arrows and add bindings
    [main.py]
2024-08-07 Add v2 of tire visual for GUI
2024-08-10 Reorder labels and add reset on serial port disconnect
    [main.py]
2024-08-10 Add hardcoded temperature reading for demo
2024-08-14 Add PCB power analysis excel file
    [PCB Power Analysis for Verification and Validation Doc.xlsx]
2024-08-16 Add video and enclosure
    [1.SLDPRT, 142-0701-801.SLDASM, 830108288709.SLDASM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]
2024-08-16 Add readme for enclosures
    [top_cover.STL]
2024-08-16 Update README.md
    Rename `enclosures` to `enclosure` in README document.

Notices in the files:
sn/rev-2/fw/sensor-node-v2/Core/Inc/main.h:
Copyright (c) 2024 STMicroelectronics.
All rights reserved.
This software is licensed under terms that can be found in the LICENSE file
